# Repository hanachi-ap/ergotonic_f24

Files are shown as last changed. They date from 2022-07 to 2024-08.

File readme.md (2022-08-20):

# Ergotonic F24

Ergotonic F24 comes with a unique adjustable centerpiece making this keyboard split or monoblock on demand.
The Ergotonic F24 extends 30 mm horizontally and allows an adjustment of ±8 degrees with regards of the slant angle. In addition, it can also be completely separated and used as a true split.

- [About Ergotonic F24](https://hanachi-ap.github.io/ergotonic_f24/) (in Japanese)

- [How to build](https://hanachi-ap.github.io/ergotonic_f24/docs/) (in Japanese)

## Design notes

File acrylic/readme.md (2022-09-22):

## これは何?
このデータは Ergotonic F24 (v1r3)に装着するアクリルプレートの加工用データです。

左右のミドルプレートおよびボトムプレート、その他の修飾用部品が定義されています。

## アクリル素材寸法  
  450mm x 300mm x 2mm

## NOTE
- ミドルプレートを装着する場合、キーボード本体 PCBの裏側に突出しているTRRSコネクタ及びリセットスイッチの足の部分をニッパーでカットし平らになるよう加工してください。

## 利用許諾

- 個人で利用される限り自由にお使いください。

- 作成したプレートの販売などお考えの場合は事前にご相談いただけると幸いです。
  (モデルチェンジ等のタイミングなどの調整のため)

- データについては下記のライセンスで配布しています
 
    Creative Commons(CC BY-SA 4.0 by Hanachi-ap)

## Change notes
v1r3_1 からv1r3_2への変更点
- ミドルプレート Right SW28付近のネジ頭逃し用の穴が欠落していたミスを修正

v1r3 からv1r3_1への変更点
- ミドルプレートの Left SW19, Right SW27付近が他パーツと干渉しないよう形状を変更
- ミドルプレート Left SW23部分が他パーツと干渉しないよう形状を変更
- ミドルプレート ネジ頭逃し用のホールを干渉しない用大きめに変更
- 全体: ロータリエンコーダ使用のためのProMicroカバーのカットデータを追加
- 全体: おまけの丸いプレートを1個追加
-

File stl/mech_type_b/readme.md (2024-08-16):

# Parts to convert Ergotronic F24 to variable-sweep wing - Type B

Wing can be folded

## Required items
- Screws M2 5mm x4
- Screws M2 30mm x2

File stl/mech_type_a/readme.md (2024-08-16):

# Parts to convert Ergotronic F24 to variable-sweep wing - Type A

## Required items
- Screws M2 5mm x4

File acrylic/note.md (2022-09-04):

## これは何?
このデータは Ergotonic F24 (v1r3)に装着するアクリルプレートの加工用データです。

左右のミドルプレートおよびボトムプレート、その他の修飾用部品が定義されています。

## アクリル素材寸法  
  450mm x 300mm x 2mm

## NOTE
- ミドルプレートを装着する場合、キーボード本体 PCBの裏側に突出しているTRRSコネクタ及びリセットスイッチの足の部分を
ニッパーでカットし平らになるよう加工してください。

## 利用許諾

- 個人で利用される限り自由にお使いください。

- 作成したプレートの販売などお考えの場合は事前にご相談いただけると幸いです。

- データについては下記のライセンスで配布しています
  - Designed by  Hanachi-ap (hanachi.ap@gmail.com)
  - Creative Commons(CC BY-SA 4.0 by Hanachi-ap)

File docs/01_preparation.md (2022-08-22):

[<<Prev: Index](index.md) 

# 1. 準備

組み立てを始める前に、パーツおよびツールが揃っていることを確認します。

## キット添付品

|品名 (基本部) | 数量 |備考|
|:---|----:|----|
|PCB (プリント基板)  右 | 1枚 |  |
|PCB (プリント基板)  左 | 1枚 |  |
|トッププレート | 2枚 | 左右共通  |
|ボトムプレート | 2枚 | 左右共通  |
|ジョイントパーツ | 2枚 | 切り離して利用|
|ネジ(短) | 32本 | M2 3mm  |
|ネジ(長) | 16個  | M2 5mm |
|スペーサー(短) | 12個 | M2 3.5mm |
|スペーサー(長) | 12個 |  M2 7mm  |
|基板用コネクタ4P | 2個  | |
|コネクタ付きコード4P | 1個  | |
|ダイオード |48個  | 1N4148W  |
|TRRSジャック |2個 | |
|タクトスイッチ |2個  | |
|クッションゴム |10個  | |

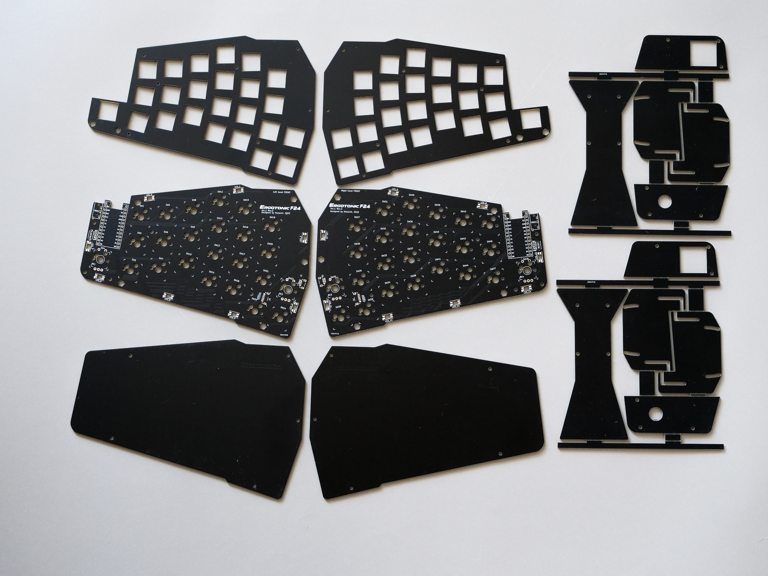
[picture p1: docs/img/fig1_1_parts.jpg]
プレート


## キット以外に用意するもの

|品名 | 数量 |備考|
|:---|----:|:---|
| ProMicro | 2個| Type-C版も可|
| コンスルー | 4個|  12ピン|
| MXスイッチソケット |48個|  |
 キーキャップ (1Uサイズ)  | 48個| |
 TRRSケーブル (4極オーディオ) | 1本 | 30cm以上推奨 |
 アンダーグロー用LED SK6812MINI-E |16個|オプション|
| ロータリーエンコーダー| 最大4個| オプション|

- 上記に上げたパーツはショップ店頭や通販で入手できます。  [パーツショップ(日本)](08_reference.md)に記した通販サイトからの購入が便利です。

- オプションと表記しているパーツは無くてもキーボードとしての基本機能は満たします。お好みに応じて準備して下さい。

- ロータリーエンコーダーは特定のキースイッチと排他で最大4個搭載できます。Alps EC12 またはEC11シリーズ互換のものを準備下さい。
日本国内で簡単に手に入るものとしては下記で動作確認しています。
   - [遊舎工房(ロータリーエンコーダ)](https://shop.yushakobo.jp/products/3762?_pos=1&_sid=5d7e3f999&_ss=r)
   - [秋月電子通商 【P-06357】ロータリーエンコーダ](https://akizukidenshi.com/catalog/g/gP-06357/)
    
   もし上記以外で動作を確認できた場合は作者にフィードバックいただけると幸いです。

## ツール
 - ハンダ道具一式
   - 糸ハンダ
   - はんだごて
   - フラックス
   - 周辺ツール(作業マット、コテ台、スポンジ、ハンダ吸い取り線、フラックス洗浄剤等)
 - ピンセット
 - 精密ドライバ(プラス No.0)
 - ラジオペンチ
 - カッターナイフ、定規、ヤスリ (PCB切り離し用) 
 - エポキシ系接着剤 (ProMicroの補強用。必要に応じて)
 - テスター  (可能なら必要に応じて)
 - 黒色のマジックペン (基板の側面の黒塗り用。必要に応じて)
  
----
[>>Next: ProMicroの準備](02_promicro.md)   

[Index](index.md)

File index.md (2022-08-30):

# Ergotonic F24 ドキュメント

Erogotonic F24は個人により開発されている自作向けメカニカルキーボードです。

## Ergotonic F24の特徴

### 左右分離型メカニカルキーボード
  - 片手 24キー 合計48キーを搭載
  - テンキー、カーソルキー、ファンクションキー、及び数字行が省かれた 40% レイアウトに相当
  - Cherry MX互換キースイッチのホットスワップに対応しているため、組み立て後も気分や状況に応じてスイッチを取り替えることが容易です。
 
### Willow配列
  - 緩やかにカーブを描いた独特のキー配列は、従来は3D構造でしか実現できていなかったエルゴノミクス的なエクスペリエンスを平面上の構造に再現しています。
  - それぞれの指を動かす際の動的な軌跡に最適化しており、目的のキーに指がすっと自然に到達する感覚が得られます
  - 親指周りに潤沢にキーを配置し、スペースキー以外にシフトキー、コントロールキーなどよく利用するキーを親指でコントロール可能とするレイアウトです
  
### 合体&変形ギミック
  
  分離型のキーボドードを一体型として利用するためのパーツを同梱。組み立て後も分離型、一体型どちらにも容易に移行できます。  また更に 左右に拡張、上下に角度をつける機構が組み込まれているので、利用者の着座姿勢や打鍵ポジションに応じてキーボードの形状を自在に変化させることができます

  -  分離型
     
     普通のスプリットキーボードとして、自在な置き方で利用できます
  
  -  一体型
  
     左右を合体させた場合は、定評のあるErgotonic49 とほぼ同じ形状となります 
  
  -  拡張形態
     
     一体型の基本形から左右に 最大30mm拡張
  
  -  前進翼形態
     
     あるいは翼を広げた鳥のようなシルエット
  
  -  後退翼形態
     
      または未来少年コナンに登場する飛行要塞ギガント

### 光るキーボード
  - アンダーグローLED(オプション)が艶やかな光でデスクを演出します

### フルキーカスタマイズ
  - すべてのキーは自由にカスタマイズが可能
  - 画面上でキーをドラッグ&ドロップするだけの簡単操作です
  - Chromeブラウザ上で操作できるため専用のアプリのインストールは不要です
  - アーダーグローLEDの光の設定やマクロ文字列の定義も簡単に行なえます 

### ロータリーエンコーダーを搭載可能
  - オプションで最大4個のロータリーエンコーダーを搭載することができます(キースイッチと排他)
  - ロータリーエンコーダーは、 拡大/縮小、上下スクロール、左右スクロール、キャンパス回転、ブラシ拡縮、音量ボリューム調整など、多彩な機能をユーザの好みで自在に割り当てることができます。

### オーソドックスな組立方式
  - 日本の自作キーボード界隈でよく採用されているFR4プレート3枚のサンドイッチ構造
  - マイクロプロセッサには入手性と取り扱いが容易なProMicroを採用
  - ファームウェアには多彩な機能が実装可能なQMK Firmwareを採用

## 作成方法

- [ビルドガイド](docs/index.md)

  - これは利用者自らが組み立てを行う必要のあるキットとして頒布されます。
  - キーボードの組み立てを始める前に全体工程をよく理解してから取りかることをおすすめします。

## 権利関係など

下記のライセンスにて公開します

  - QMK Firmware -- GPL v2
  - PCB デザイン -- GPL v3
  - [キー配列(Willow配列)](docs/ergotonic_f49_layout_desigen.pdf )-- Creative Commons(CC BY-SA 4.0 by Hanachi-ap)   

## ベースとなったプロダクト
  - Ergotonic49 
    - Ergotonic F-24と同じ開発者による現行モデル
    -  ドキュメント https://hanachi-ap.github.io/ergotonic49_docs/
    -  紹介記事 https://coal.hatenablog.com/entry/2021/11/01/230327
  - PANGAEA Keyboard
    - 開発リソース https://github.com/e3w2q/Pangaea-keyboard
    - 開発陣 e3w2qさん、オタヒーのさめさん、k2さん
    - 変形機構のアイデアや実装を借用しています
    - PCB設計のための部品ライブラリを利用させてもらっています
    - その他、豊かな発想から開発の養分を得ています
  
変形ギミックが特徴的なキーボードですが、その変形機構は[PANGAEA Keyboard](https://github.com/e3w2q/Pangaea-keyboard)が発想の源となっています。
一体型、分離型のトランスフォームはWillow64を始めた頃からやりたかったことですが、やっとその目標を結実することができました。
変形機構の利用を快諾していただいたPANGAEAキーボードの開発陣に謝意を送ります。

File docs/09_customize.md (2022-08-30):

# キーボードをカスタマイズする

##  標準キーマップ

標準ファームウェアでは0から4までの5つのレイヤーが定義されています。

 - レイヤー0  : 基本のアルファベット
 - レイヤー1  : 未定義
 - レイヤー2  : 数字、記号
 - レイヤー3  : カーソル移動、ファンクションキー
 - レイヤー4  : LED操作などキーボードシステム設定

Erogotonic49には物理的な数字キーはありませんが、レイヤー変更キーを押しながらQを押すと1が入力されるというような動作が可能です。

また レイヤー1 はなにもキーコードが定義されていない状態になっています。これはWindowsとMacの使い分け、オフィス作業とゲーム操作の使い分け、特定のアプリのショートカットなど自由に定義できるレイヤーとして使って下さい。

その他にも色々な機能があるので、 チートシート [keymap_cheatsheet_ergotonic_49.pdf](img/keymap_cheatsheet_ergotonic_49.pdf)を参照して確認してみて下さい。

----
自分が使いやすいと思うように自由にカスタマイズすることは自作キーボードの楽しみの一つなので、標準キーマップにとらわれず色々と試してみるのが良いと思います。

Ergotonic49をカスタマイズする方法は、大きく次の2つの方法があります。
  1. [REMAP](https://remap-keys.app/)を用いて、直感的にキーマップを変更する方法
  2. [QMK Firmware](https://docs.qmk.fm/)を編集して詳細なカスタマイズを行う方法

## 1. REAMPをつかう

キー配列を変更したり、LEDの点灯を変更したりするにはREMAPがあれば十分だと思います。

キーボードとPCをつないだ状態でChromeブラウザで[https://remap-keys.app/](https://remap-keys.app/)にアクセスして下さい。

サイトは英語表記だけですが、操作方法は直感的なので特に説明が無くても解ると思います。アカウント登録するとキーマップを保存したり読み込んだりできるので便利です。

## 2. QMK Firmwareを編集する

Ergotonic F24は[QMK Firmware](https://docs.qmk.fm/)というオープンソースとして開発されているファームウェアを利用しいています。

QMKにはとても沢山の機能が用意されていて、より自由な設定を行うことができます。
しかしそのためにはプログラミング言語(C言語)やPC上での黒い画面(コンソール)でコマンドを使ったコンパイル操作を行う必要があります。

Ergotonic F24のファームウェアは [ここ](https://github.com/hanachi-ap/ergotonic_f24)から参照できます。
もしこれを見て行けそうだ! と感じたらぜひQMK Firmwareのカスタマイズに挑戦してみて下さい。

----
 [Index](index.md)

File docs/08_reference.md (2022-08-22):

 [Index](index.md)

# 参考情報

## パーツショップ(日本)

キット以外に必要なパーツは自作キーボードの代表的な下記ショップで揃えることができます。

- 遊舎工房 [https://yushakobo.jp/](https://yushakobo.jp/)
- TALP KEYBOARD [https://talpkeyboard.stores.jp/](https://talpkeyboard.stores.jp/)
- LiLaKEY [https://lilakey.com/](https://lilakey.com/)
- 秋月電子通商 [https://akizukidenshi.com/catalog/default.aspx](https://akizukidenshi.com/catalog/default.aspx)
  
## はんだ付け技能
下記以外にも様々なテクニックやノウハウが公開されているので、各個のスキルに応じて検索サイトで調べるようにしてください。

- [はんだ付けテクニックを学ぼう](https://handa-craft.hakko.com/) HAKKO
- [電子工作のコツ/はんだ付け ](https://article.murata.com/ja-jp/article/soldering)村田製作所
- [ハンダ付け職人のはんだ付け講座](https://godhanda.co.jp/blog/category/handakouza/soldering%E3%80%80guide/) ゴッドはんだ株式会社
- [表面実装部品（SMD）のはんだ付け](https://www.kogadenshi.co.jp/%E5%8D%8A%E7%94%B0%E4%BB%98%E3%81%91%E3%83%86%E3%82%AF%E3%83%8B%E3%83%83%E3%82%AF/%E8%A1%A8%E9%9D%A2%E5%AE%9F%E8%A3%85%E9%83%A8%E5%93%81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) 株式会社古賀電子

----
 [Index](index.md)

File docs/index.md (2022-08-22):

# Ergotonic F24 組み立て説明書

Ergotonic F24のビルドガイドです。

キーボードの組み立てを始める前に全体工程をよく理解してから取りかることをおすすめします。

## TOC

1. [準備](01_preparation.md)  
2. [ProMicroの準備](02_promicro.md)
3. [PCBへのパーツ取り付け](03_soldering_pcb.md)
4. [組立前の動作確認](04_operation_check.md)
5. [組み立て](05_assembly.md)
6. [最後のステップ](06_final_step.md)
7. [トラブルシュート](07_troubleshoot.md)

- [Ergotonic F24の使い方、キーマップのカスタマイズ方法](10_usage.md)
 
- [参考情報(外部リンク)](08_reference.md)

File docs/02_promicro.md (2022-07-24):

[<<Prev: 事前の準備](01_preparation.md)  

# 2. ProMicroの準備

## ProMicroにコンスルーをはんだ付けする

- スプリングピンヘッダの足の長い方をPCBのスルーホールへ差し込みます。
- ProMicroの部品が実装してある面が内側に隠れるような向き(平らな面が見える向き)でピンヘッダに差し込みます
- ProMicro側のピンヘッダをはんだ付けします。

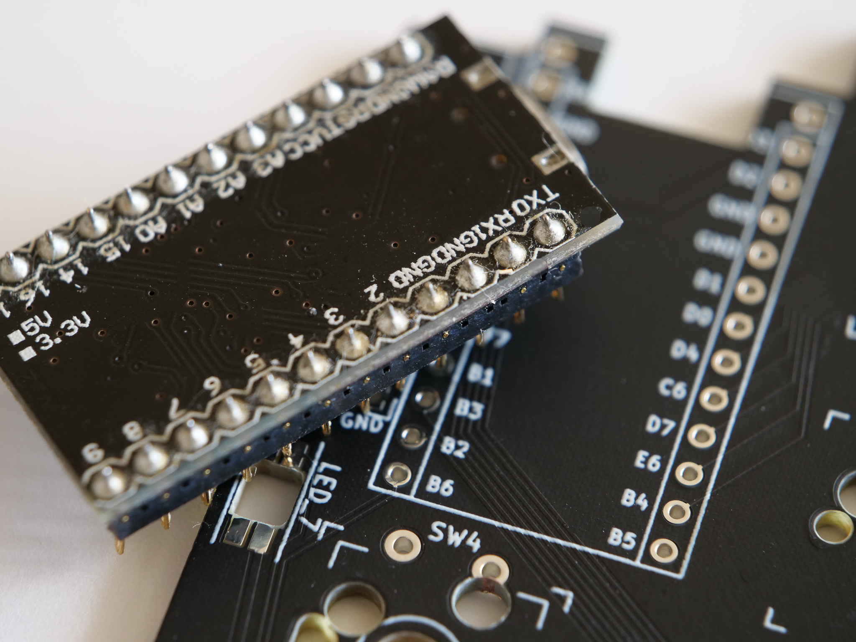
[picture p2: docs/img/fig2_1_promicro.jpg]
ProMicro
  

NOTE
- PCB側のピンヘッダははんだ付けしません。はんだ付けするのはProMicro側だけです。
- ProMicroの表裏を間違えるとリカバリが非常に大変ですのではんだ付けの前に向きに注意ください。

TIPS:
 - [ProMicroへコンスルーの取り付け方(遊舎工房)](https://yushakobo.zendesk.com/hc/ja/articles/360044233974-%E3%82%B3%E3%83%B3%E3%82%B9%E3%83%AB%E3%83%BC-%E3%82%B9%E3%83%97%E3%83%AA%E3%83%B3%E3%82%B0%E3%83%94%E3%83%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)

## USBコネクタ周辺を補強する(オプション)

ProMicroはUSBコネクタ部分の強度が弱いことが知られています。
対策としてProMicroのUSBコネクタ部分をエポキシ系接着剤の樹脂で強化します。
 - エポキシ系接着剤の説明書の指示通りに調合し、爪楊枝の先などで慎重にUSBコネクタ周辺に盛り付けます。
 - 樹脂が硬化するまで安静にします。

TIPS:
  - [もげマイクロ対策(Google search)](https://www.google.com/search?client=firefox-b-d&q=%E3%82%82%E3%81%92%E3%83%9E%E3%82%A4%E3%82%AF%E3%83%AD)
  - 2液タイプのエポキシ系接着剤は100円ショップでも手に入ります。

----
 [>>Next: PCBへのパーツ取り付け](03_soldering_pcb.md)

 [Index](index.md)

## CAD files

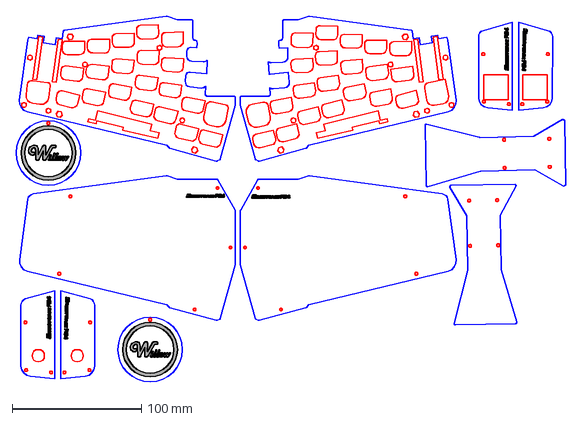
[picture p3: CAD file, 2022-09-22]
acrylic/ergotonic_f24_v1r3_2_acrylic_cut.dxf
425.9 x 283.2 mm

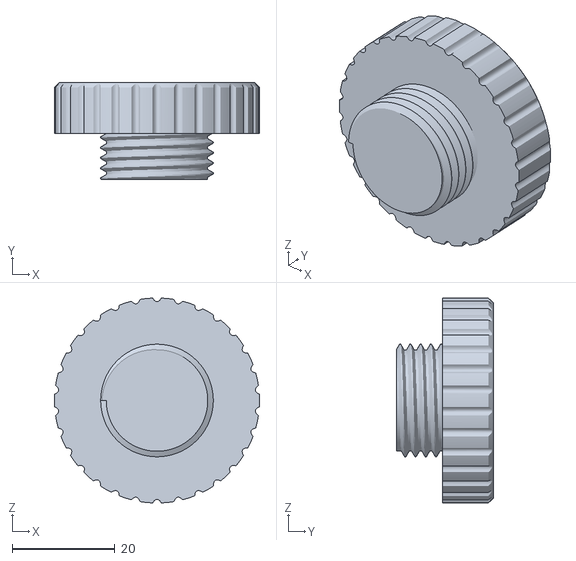
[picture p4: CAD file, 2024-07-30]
stl/mech_type_a/f24 - knob.stl
40.0 x 19.0 x 40.0

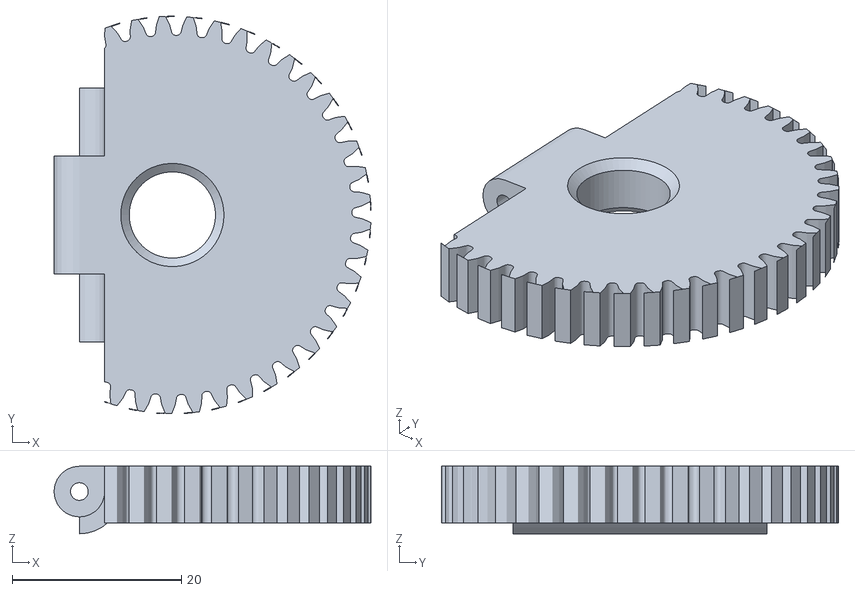
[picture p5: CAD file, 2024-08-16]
stl/mech_type_b/f24 - gear-r.stl
37.5 x 47.0 x 8.00

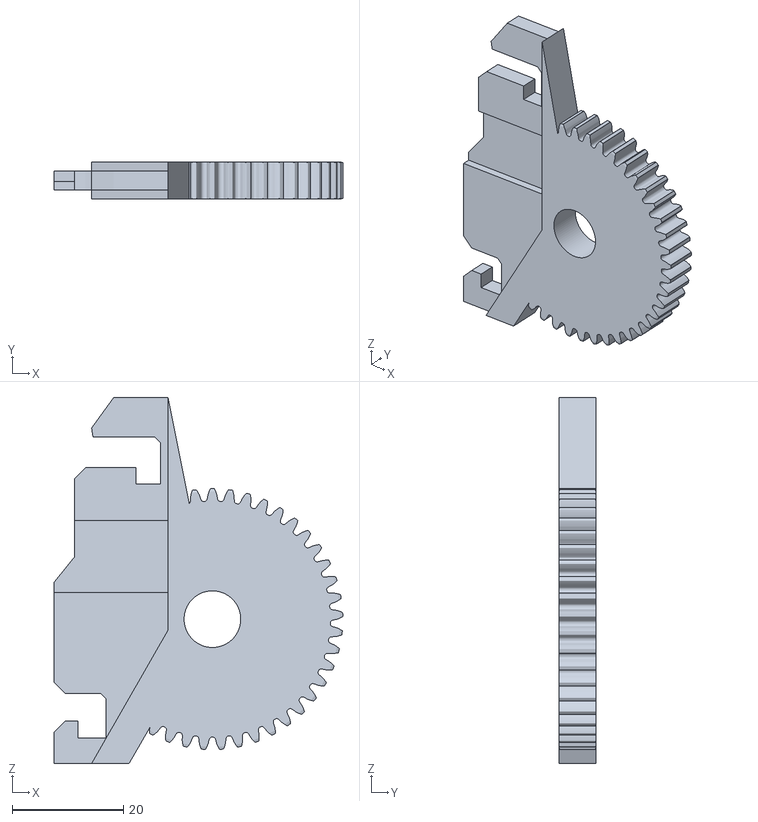
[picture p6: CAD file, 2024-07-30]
stl/mech_type_a/f24 - wheel-l.stl
52.0 x 6.70 x 65.9

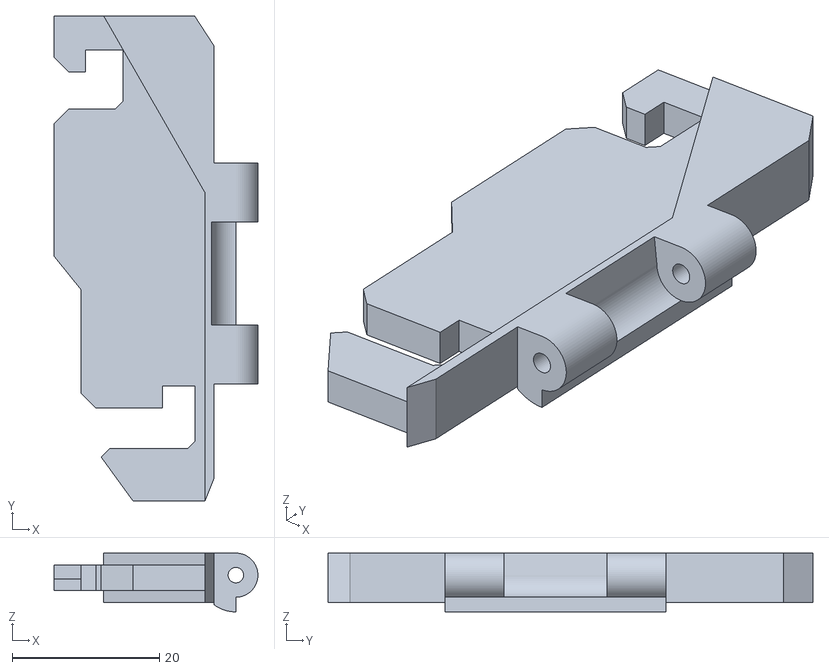
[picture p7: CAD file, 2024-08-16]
stl/mech_type_b/f24 - drumette-l.stl
27.7 x 65.9 x 8.00

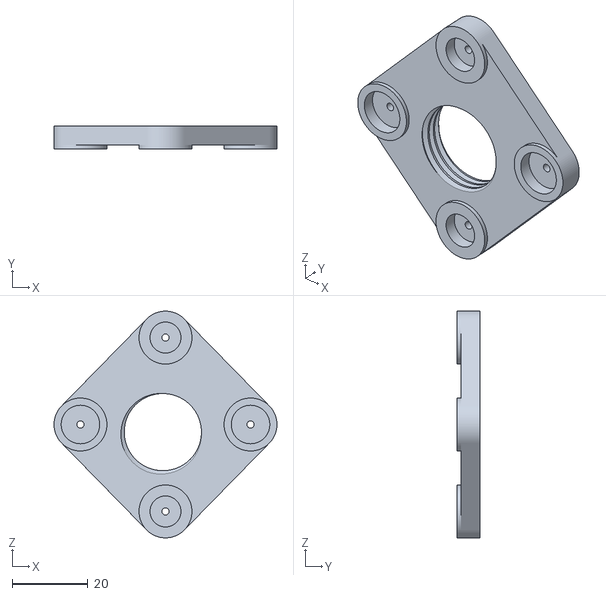
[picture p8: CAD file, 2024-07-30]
stl/mech_type_a/f24 - top.stl
59.0 x 6.00 x 60.0

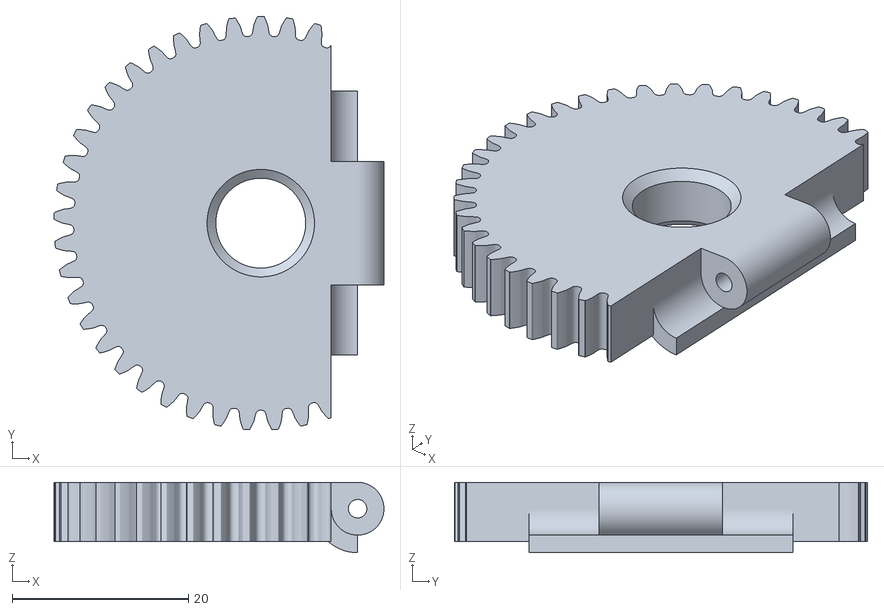
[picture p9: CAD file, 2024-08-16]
stl/mech_type_b/f24 - gear-l.stl
37.5 x 47.0 x 8.00

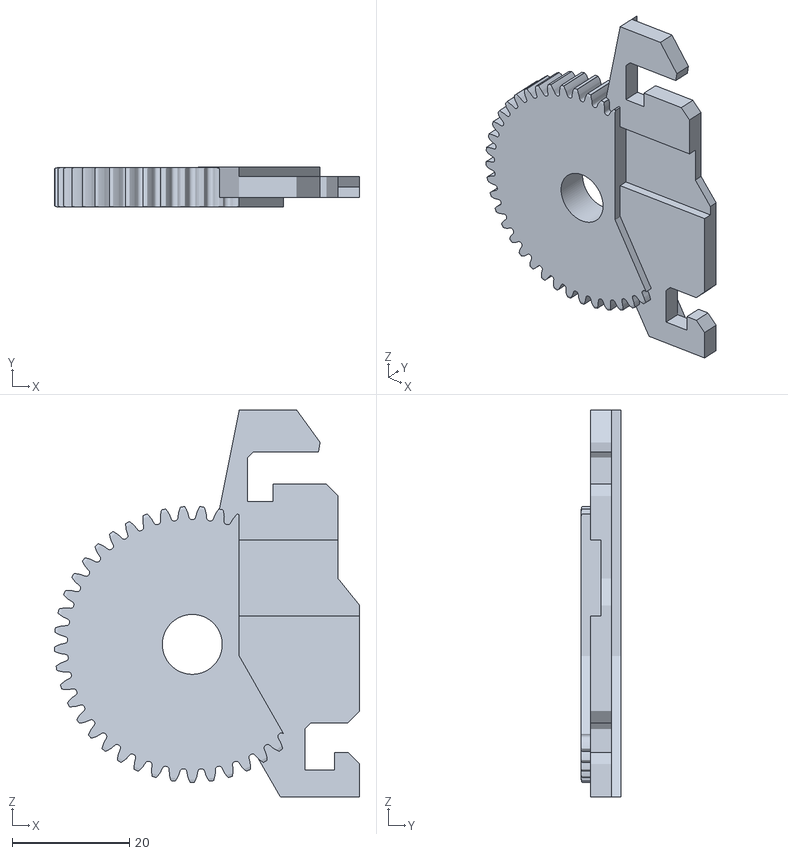
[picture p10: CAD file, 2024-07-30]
stl/mech_type_a/f24 - wheel-r.stl
52.0 x 6.80 x 65.9

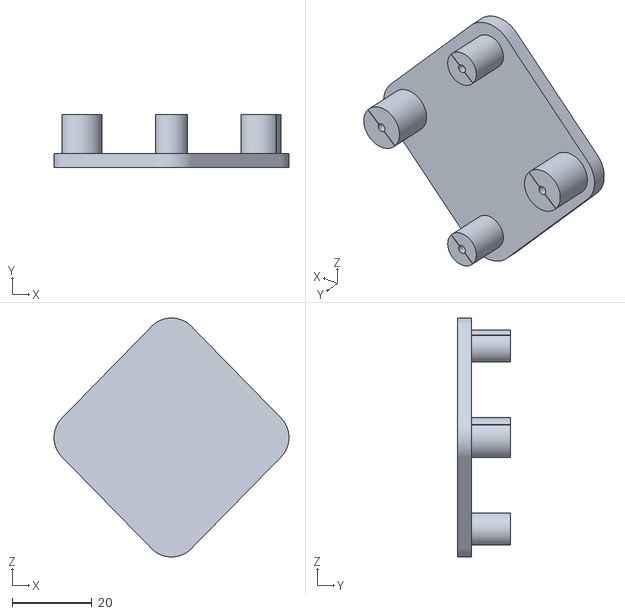
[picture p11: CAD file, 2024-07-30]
stl/mech_type_a/f24 - base.stl
59.0 x 13.2 x 60.0

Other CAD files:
stl/mech_type_b/f24 - drumette-r.stl

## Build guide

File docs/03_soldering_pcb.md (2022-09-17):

[<<Prev: ProMicroの準備](02_promicro.md)  

# 3. PCBへのパーツ取り付け

- PCBは、左側と右側で種類が分かれています。このページの操作は左右それぞれのPCBに対して作業を行ってくだい。

- PCBへのパーツを取り付ける際にはPCBの左右、表裏に注意して下さい。プリントされている表記で判断出来ます。

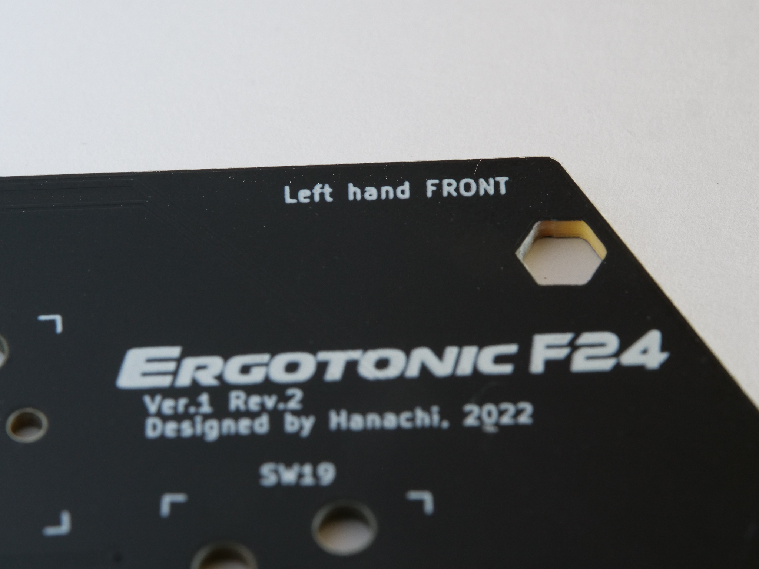
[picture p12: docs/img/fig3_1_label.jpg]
   

## ダイオードをはんだ付けする

電流の流れを制御するダイオードをはんだ付けします。

- ダイオードはPCBの裏面から取り付けます。
- ダイオードには極性があります。LEDに薄い線が印刷されている方向(カソード)をPCBシルクに合わせて配置します。
  
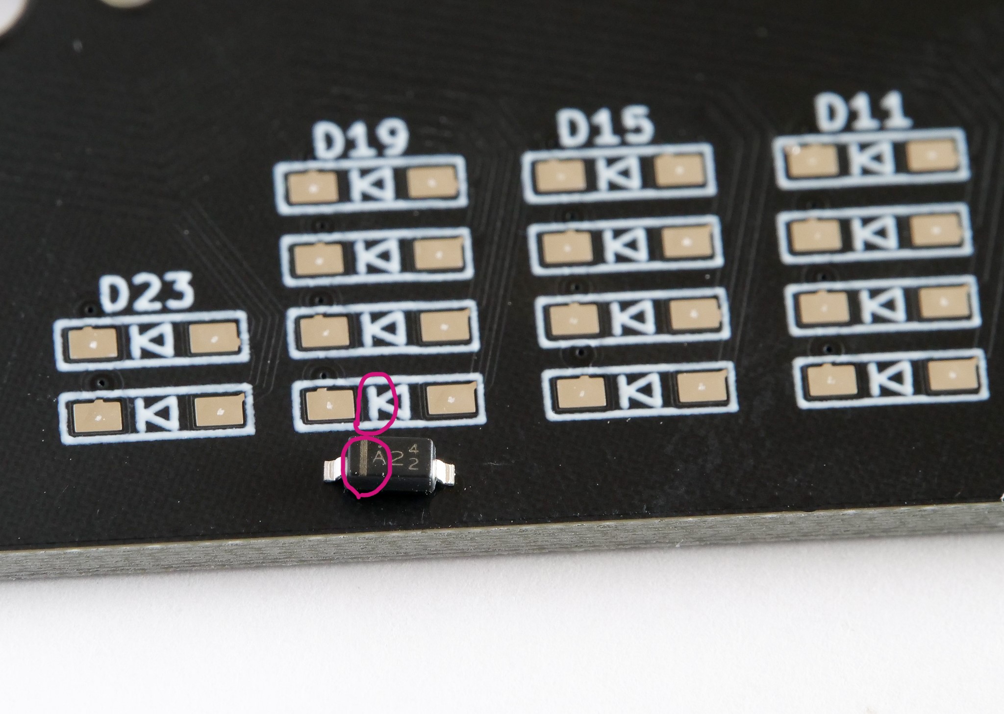
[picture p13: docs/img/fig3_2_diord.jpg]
   

- 両端2ヶ所をはんだ付けします。

TIPS:

- SMD型ダイオードのはんだ付けのコツ
  - PCBのパッドの片方に予備ハンダを盛ります
  - 予備ハンダを溶かしつつピンセットでダイオードを所定の位置に送ります
  - 反対側をはんだ付けします
  - 予備ハンダをした方をもう一度はんだ付けします
  
NOTE:

 - ダイオードの方向を間違わないよう気をつけて下さい。
 - キーが反応しないというトラブルの多くはダイオードのハンダ不良に起因します。はんだ付けの後に目視確認をしっかり行って下さい。
   - ハンダを忘れている部分がないか
   - はんだ付け不良の部分はないか
   - ダイオードの方向に間違いはないか

## アンダーグローLEDをはんだ付けする(オプション)

キーボードの下を装飾するアンダーグローLEDをはんだ付けします。

- PCBの裏面のLED_0、LED_1、LED_2とシルク印刷されている箇所に取り付けます。
  - PCBの表側から、光る面が裏側(下向き)になるように配置します。
  - LEDには極性があります。LEDの足が欠けている方向をシルクの印に合わせます。
  
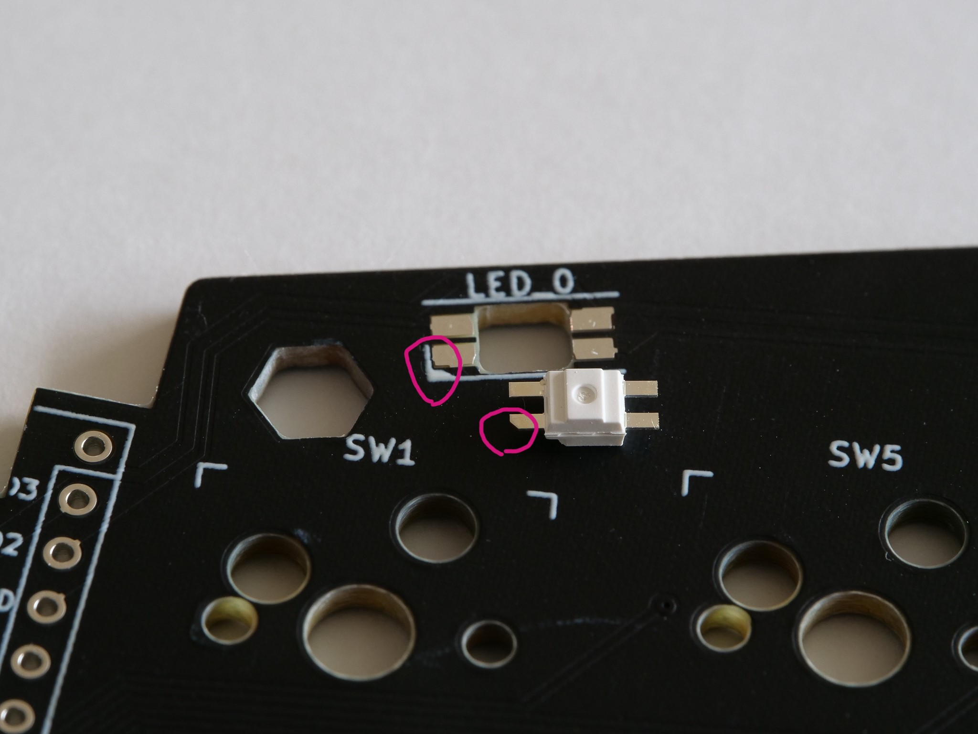
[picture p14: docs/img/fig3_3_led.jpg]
  

-  LEDの4ヶ所の足をはんだ付けします。

TIPS:

- LEDの取り付けと同時に光るかどうかを確認していくにはProMicroの環境を先に整えて、LED設定を RGB TESTモードに設定すると確認が行いやすくなります。

NOTE:

 - LEDの表裏、方向を間違わないよう気をつけて下さい。
 - 一度はんだ付けした後だと取り付け方向を修正するのは非常に困難になります。
  はんだ付けの前にしっかりと取り付け方向が正しいことを確認するようにして下さい。
 - RGB LEDは熱に弱いため、高温で長時間はんだ作業をしないよう注意して下さい。
 - LEDは番号の順に数珠つなぎで接続されています。光らない場合は番号順に調べていくようにしてください。

トラブルシュート:
  - [LEDが点灯しない](07_troubleshoot.md)

## スイッチソケットをはんだ付けする

キースイッチを取り外し可能にするソケットをはんだ付けします。

- PCBの裏面からシルクに合わせて取り付けて、2ヶ所をはんだ付けします。
  
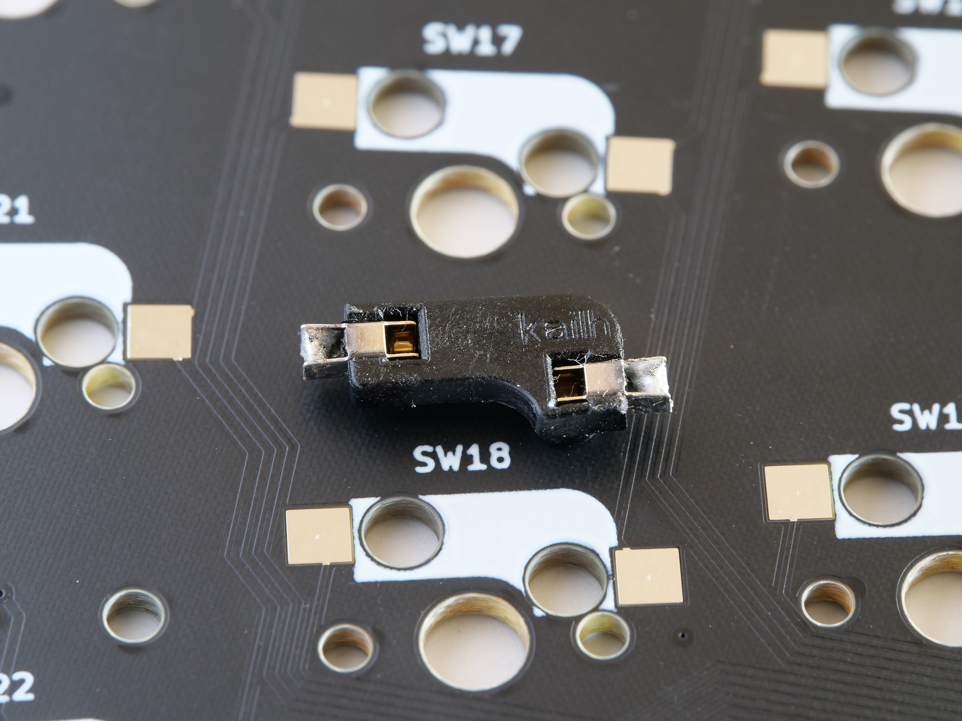
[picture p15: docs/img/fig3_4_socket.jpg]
MXスイッチソケットは裏側からはんだ付け
  

## リセットスイッチをはんだ付けする

- PCBの表側からタクトスイッチを取り付けます(極性はありません)
- PCBの裏側からはんだ付けします
  
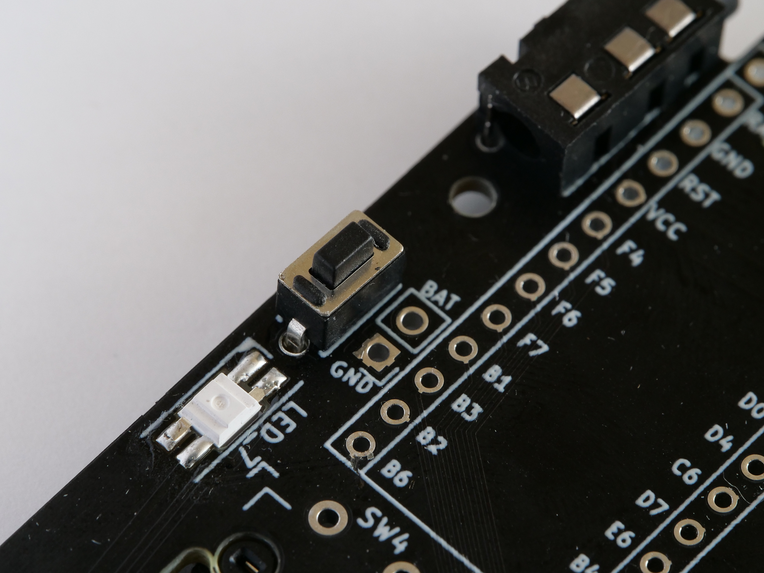
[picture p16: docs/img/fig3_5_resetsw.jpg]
リセットスイッチは表から挿して裏からはんだ付け
  

## TRRSジャックをはんだ付けする

- PCBの表側からタTRRSジャックを取り付けます。
- PCBの裏側からはんだ付けします
  
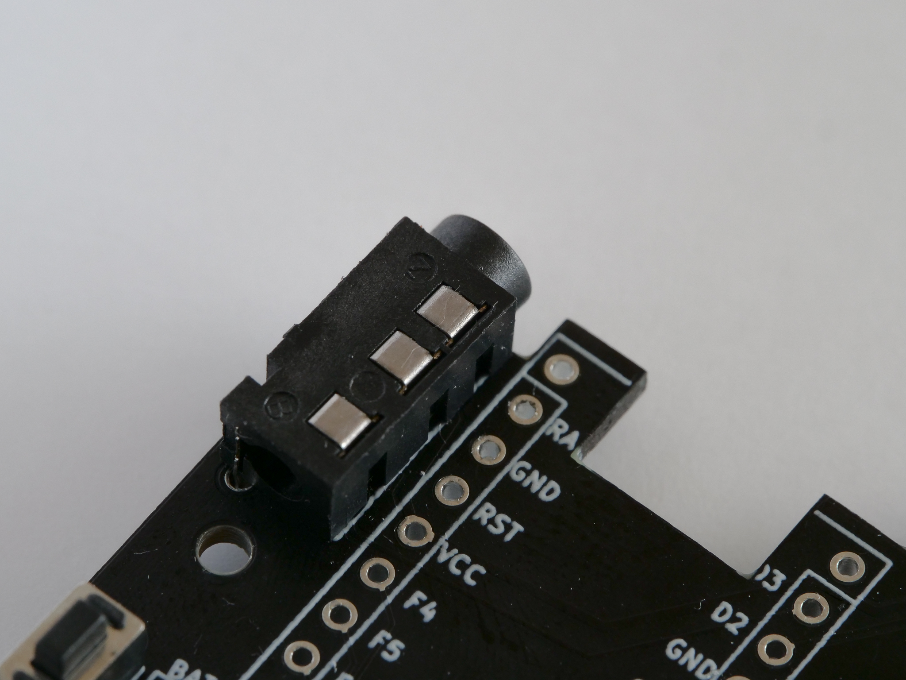
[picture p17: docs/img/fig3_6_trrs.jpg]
TRRSジャックは表から挿して裏からはんだ付け
  

## 基板用コネクタをはんだ付けする

- 左右のPCBをケーブルで結ぶためのコネクタをはんだ付けします。
- 若干難易度が高いので注意しながら進めてください。

下記は、作者が行っている方法です。

- PCBの表側に部品の位置を合わせマスキングテープで仮止めします

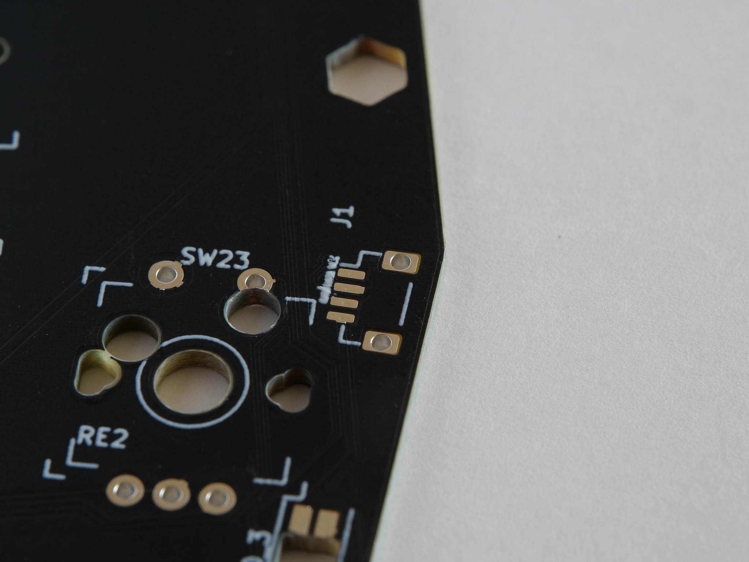
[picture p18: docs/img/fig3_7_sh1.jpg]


- PCBのパッドとコネクタの足の位置をしっかり見定め、コネクタの足を一本だけはんだ付けします
  - 2本以上の足をはんだ付けしてしまうと位置のリカバリが難しくなるので注意
  - この状態でコネクタを動かすとパッドごと剥がれてしまうことがあるので無理に動かさないように注意
- PCBの裏側のスルーホールからハンダを流し込みます。
  - スルーホールを通って表側までハンダが到達しコネクタをしっかりと接着していることを確認してください。
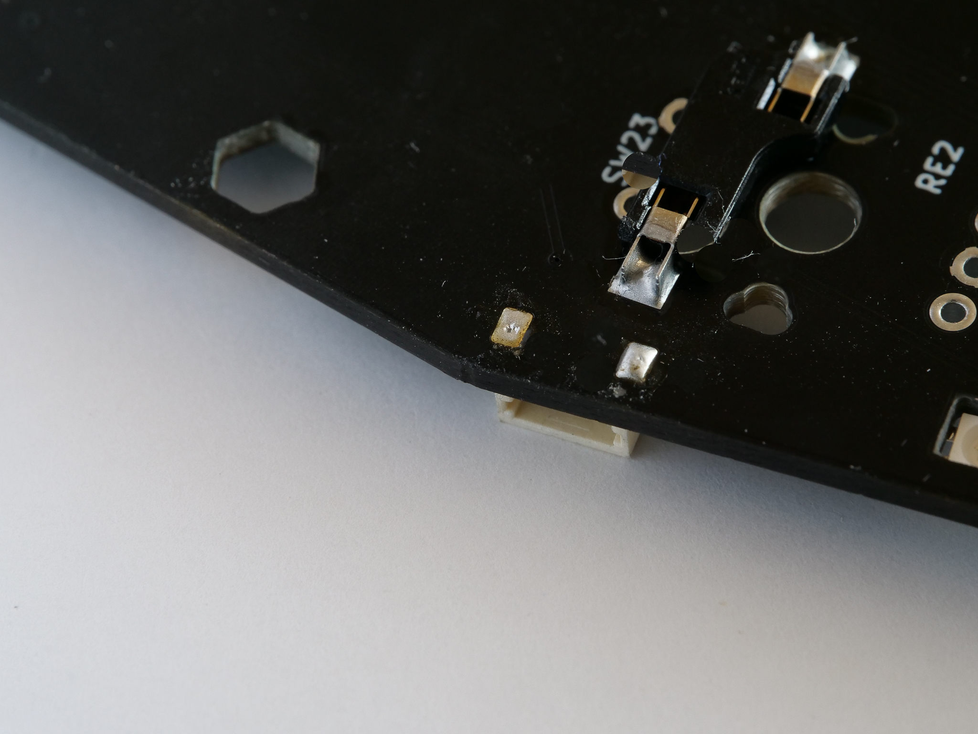
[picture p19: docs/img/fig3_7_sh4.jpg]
   

- PCB表側からコネクタの足の残りをはんだ付けします
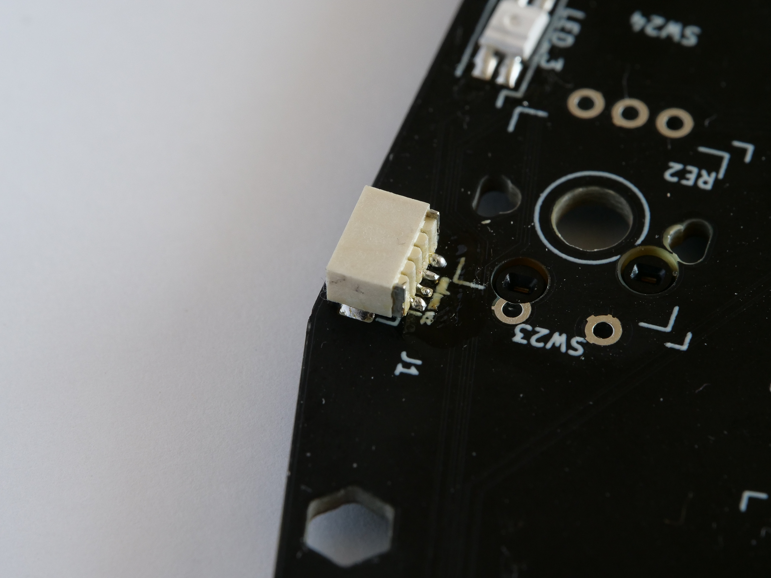
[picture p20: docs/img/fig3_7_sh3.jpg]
   

- TIPS

  基板端子のはんだ付けのショートムービを参照してください
  https://www.youtube.com/shorts/smUXss702QM

#### 注意
- 基板用コネクタにケーブルを差し込む前に、コネクタがしっかりとハンダで固定されれていることを確認するようにしてください。
- コネクタがしっかりと固定されていない状態でケーブルを差し込むと、基板からのネクタがポロッと外れてしまうだけでなく
  PCB内部の配線パターンごと剥がれてしてしまい、リカバリ不能な破損に繋がります。

## ロータリーエンコーダーを取り付ける

- ロータリーエンコーダーはRE1, RE2, RE3, RE4のシルク表記がある箇所に取り付けることができます。
- PCBの表側からパーツを取り付け、裏側をはんだ付けします。

----
 [>>Next: 組立前の動作確認](04_operation_check.md)

[Index](index.md)

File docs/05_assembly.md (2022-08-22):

[<<Prev: 組立前の動作確認](04_operation_check.md)  

# 5. 組み立て

はんだ付けが終わったパーツをキーボードの形に組み上げていきます。

## ジョイントパーツを切り離す
- ジョイントプレートのパーツを切り離して端面をヤスリがけしてなめらかにします。
  
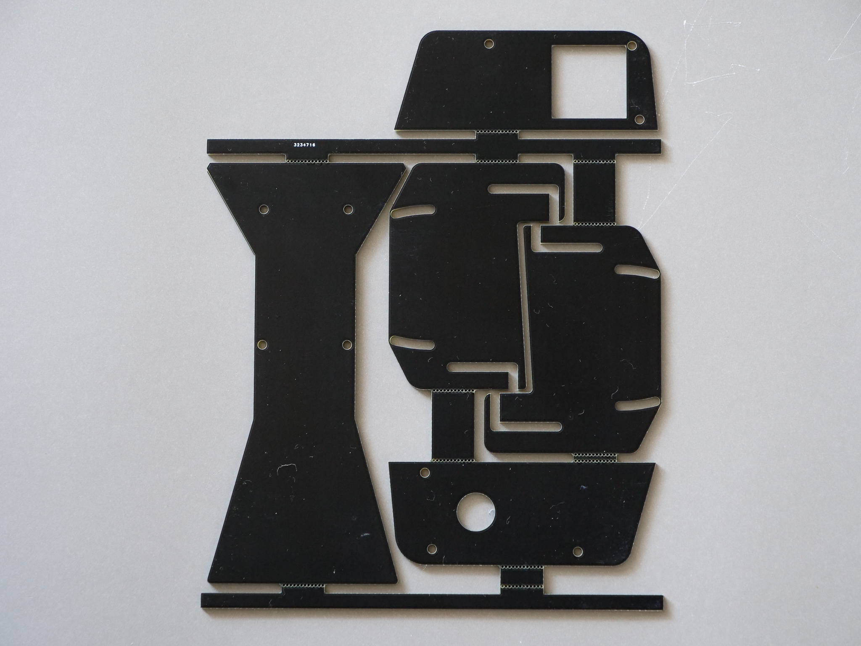
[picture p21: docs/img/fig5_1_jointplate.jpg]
  

## TIPS: 基板の側面を黒く塗る
- 基板の側面を表面と同じ黒色で塗装すると、組み立てた後にぐっと締まった佇まいとなります。オプション作業ですが、黒のマジックペンで基板側面を黒く塗ることをおすすめします

## PCBとトッププレートを結合する

- PCBにスペーサー(短)を2ヶ所ネジ止めします
  - 写真の位置に、表側にスペーサー(短)を配置し裏側からネジ(短)でねじ止めします。
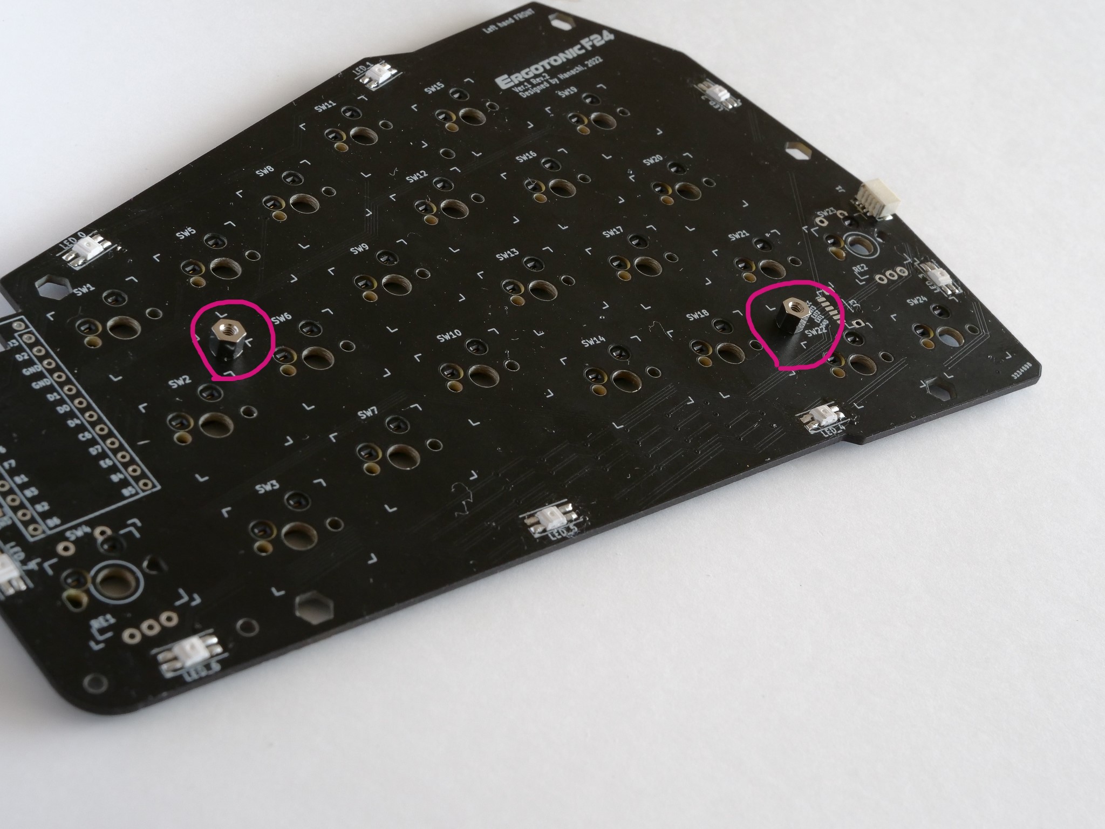
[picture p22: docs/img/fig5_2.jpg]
   
  
  - トッププレートを重ね、表側からも2ヶ所ネジ(短)でねじ止めします。
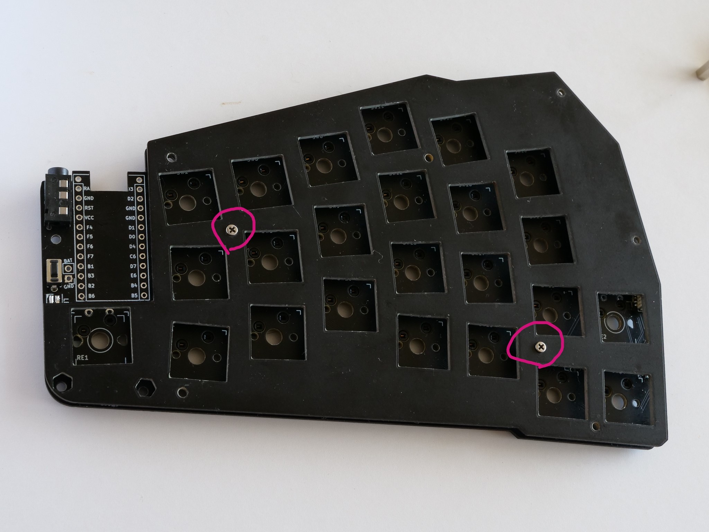
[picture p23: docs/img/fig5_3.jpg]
  

## スペーサー を取り付ける

- 全体を裏返し、PCBの六角形の穴の部分 Spacer(L)の指示の3ヶ所にスペーサー(長)を差し込みます
- PCBの六角形の穴の部分 Spacer(S)の指示の2箇所にスペーサー(短)を差し込みます。
  
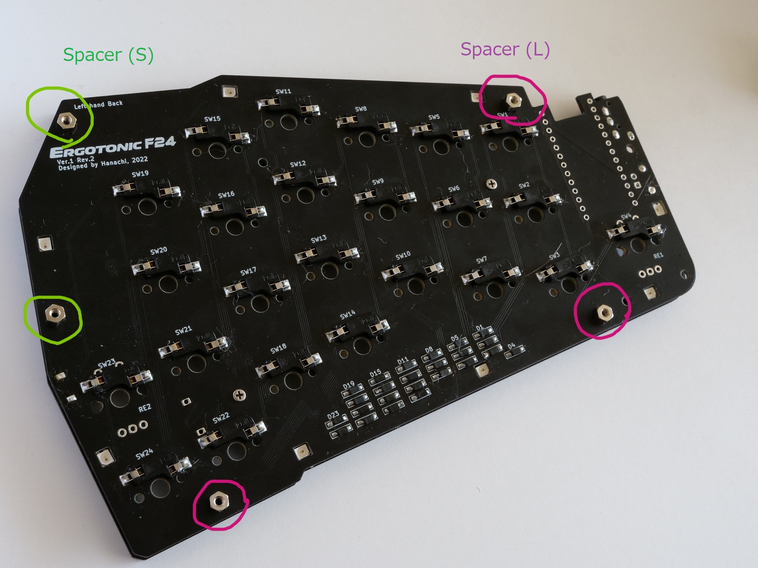
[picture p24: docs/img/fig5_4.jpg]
   
   
- トッププレート側からネジ止めします

  - Scew(S)の指示部分には、ネジ(短)を使用します
  - Screw(L)の指示部分には、ネジ(長)を使用します

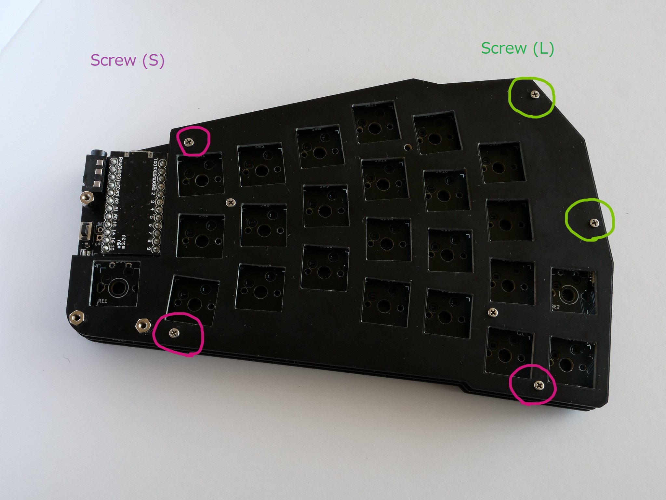
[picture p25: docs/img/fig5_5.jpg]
  

## PCBと保護プレートを結合する

- トッププレートの表側から、写真の位置にスペーサー(長)を配置し、PCBの裏側からネジ(短)で止めます
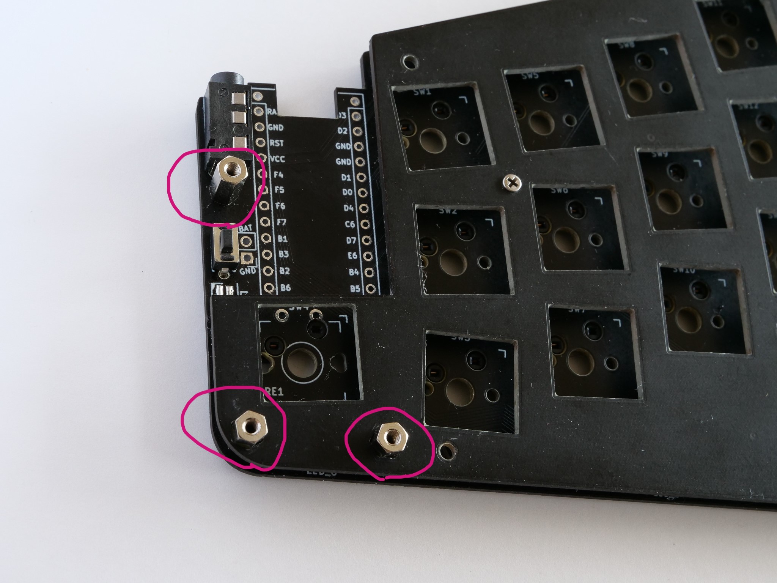
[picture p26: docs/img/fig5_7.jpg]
  
  
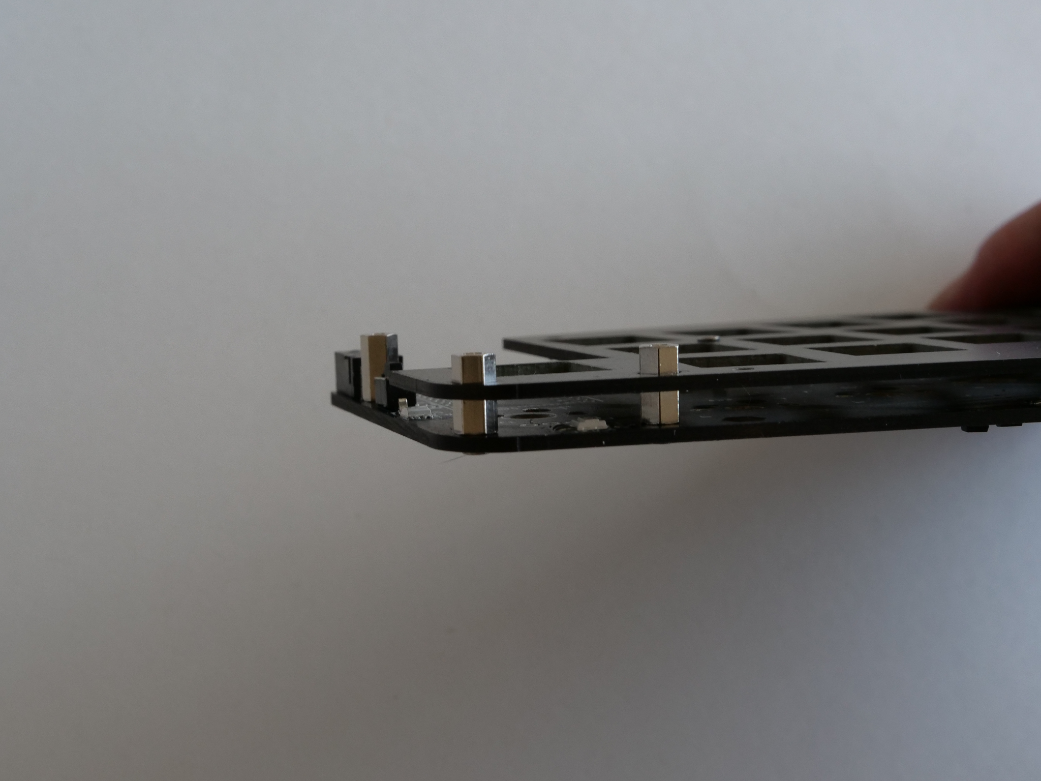
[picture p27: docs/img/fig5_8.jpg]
   

- 保護プレートを重ねて上から3ヶ所をネジ(短)で止めます。
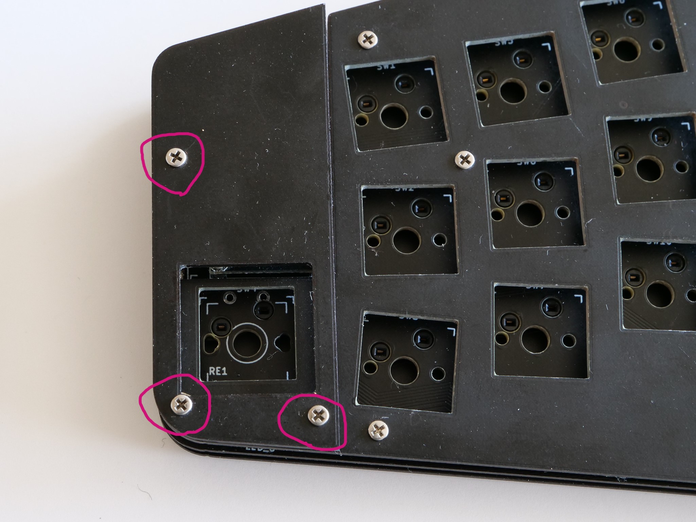
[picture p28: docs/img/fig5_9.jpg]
  

## ボトムプレートを結合する

- ボトムプレートを重ね 5ヶ所をネジ止めします
  - Scew(S)の指示部分には、ネジ(短)を使用します
  - Screw(L)の指示部分には、ネジ(長)を使用します
  - 
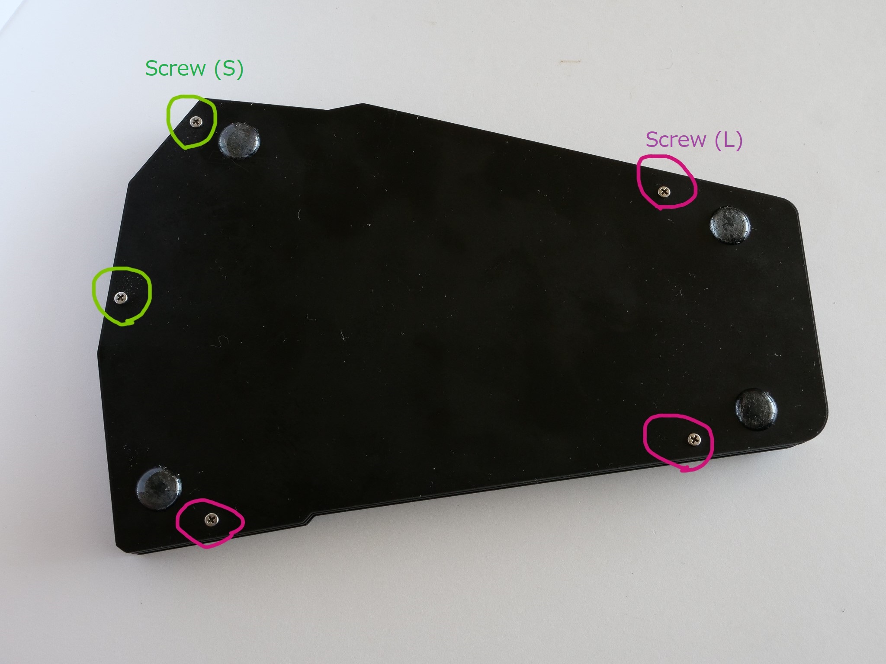
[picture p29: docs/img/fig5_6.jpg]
  

- スペーサー(短)の部分に関しては、横から見ると写真のように スペーサー(短)が中央部に浮いている状態になります。
  
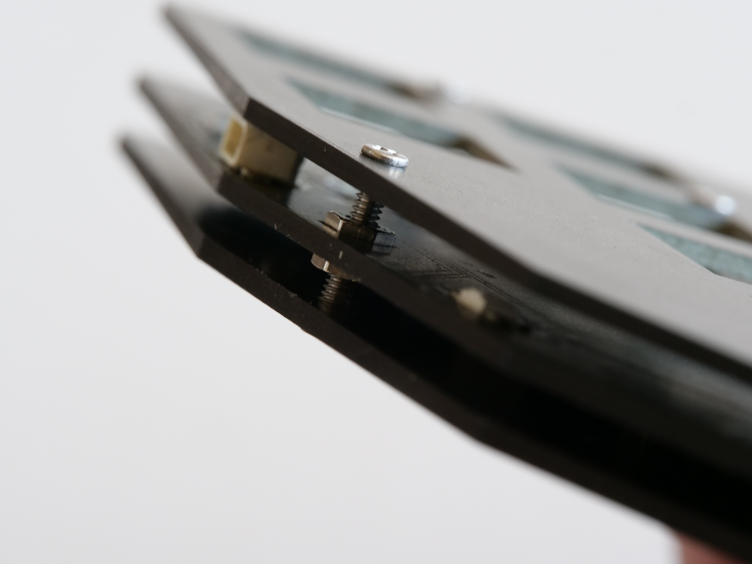
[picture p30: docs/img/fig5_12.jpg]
  

## [分離型で利用する場合]

### 三角スペーサージグを取り付ける
- プレートから切り出した三角形状のスペーサージグを2枚、プレートとスペーサー(短)の隙間に挟み込みネジを締めます。

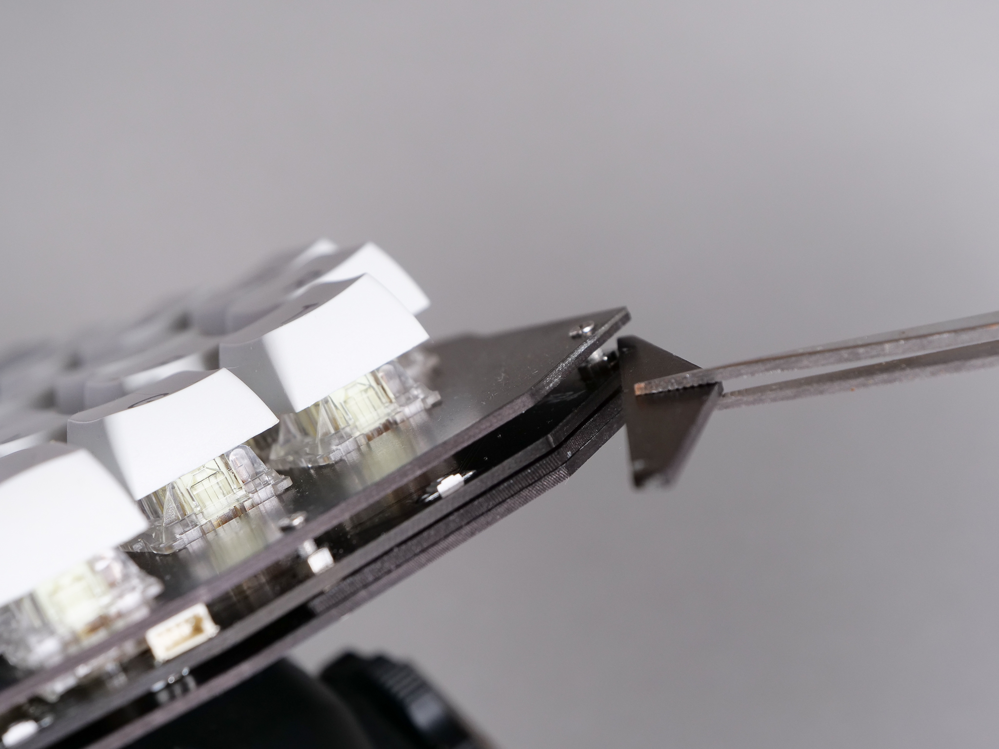
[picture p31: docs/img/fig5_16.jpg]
  

## [一体型で利用する場合] 

### ジョイントプレートを結合する

- ジョイントプレートをスペーサー(短)とネジ(長)を使い、図のように組み立てます
  
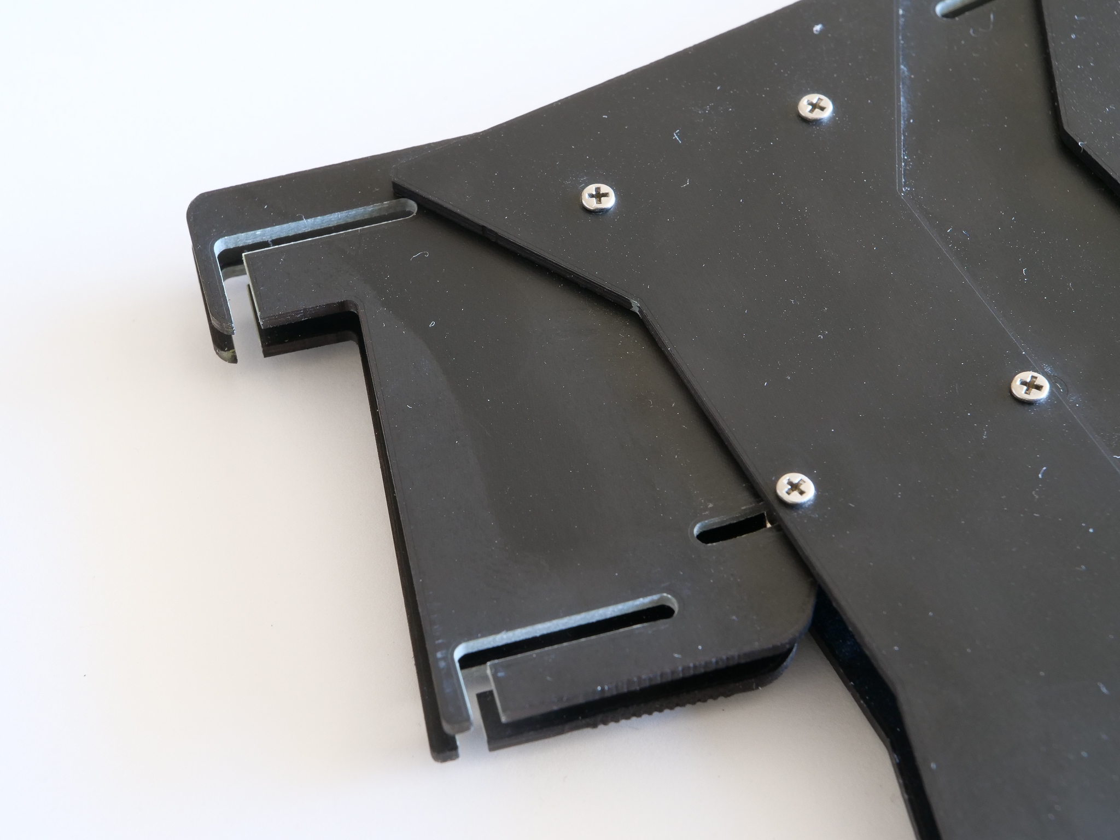
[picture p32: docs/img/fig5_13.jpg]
  

- ジョイントパーツのスリット部分を、先程のスペーサー(短)の隙間に通します。
  
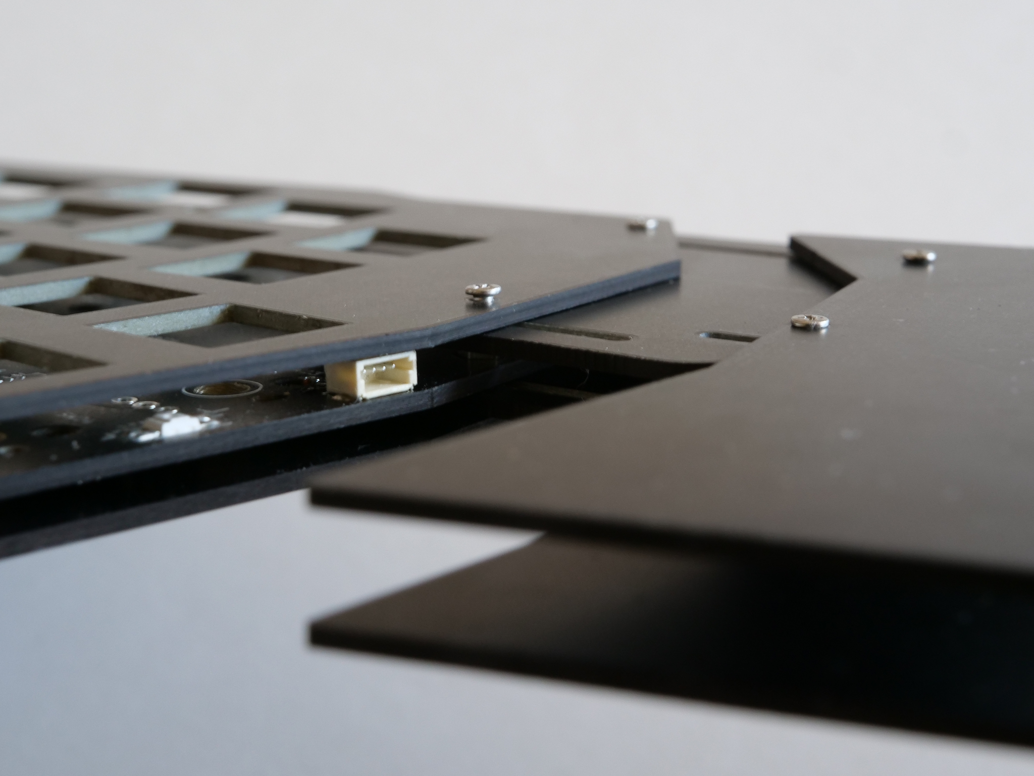
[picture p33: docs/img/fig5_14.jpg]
  

- コネクタ付きコード4Pをソケットに挿して左右を接続します。
  
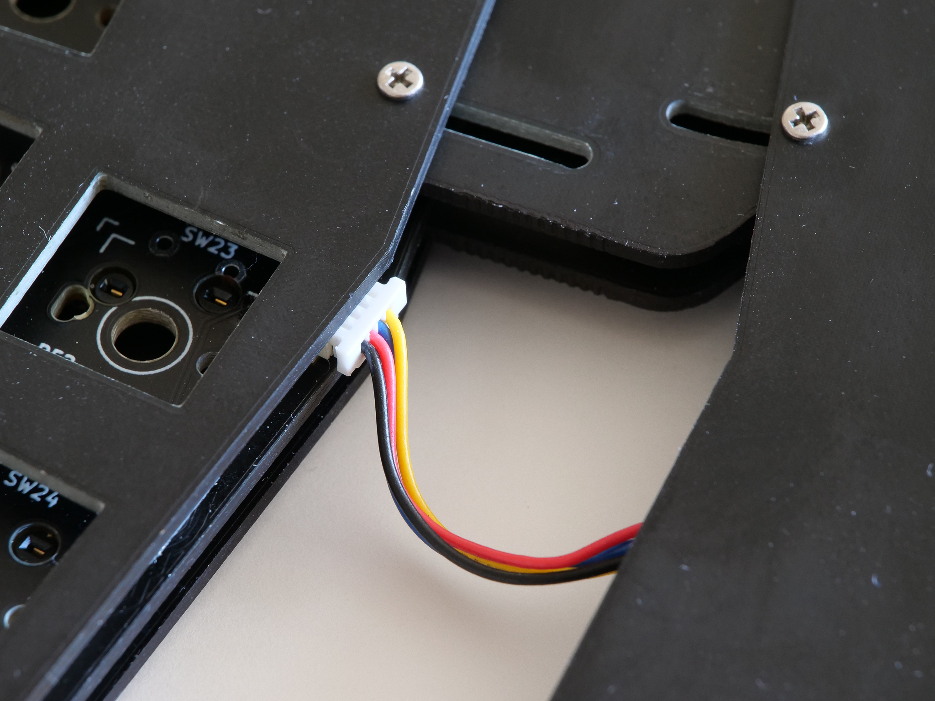
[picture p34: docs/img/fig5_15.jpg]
  

- ネジの締付けを調整しつつ好みの位置で固定します。
  
## ゴム足を取り付ける

- 裏側からゴム足を左右それぞれ4箇所、ジョイント部分に2箇所に取り付けます

----
 [>>Next: 最後のステップ](06_final_step.md)

[Index](index.md)

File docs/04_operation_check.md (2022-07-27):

[<<Prev: PCBへのパーツ取り付け](03_soldering_pcb.md)  

# 4. 組立前の動作確認

## ProMicroを取り付ける

PCBの表側からProMicroを取り付けます。

## ファームウェアを書き込む

下記の操作を左右2つ分のProMicroに対して行います。この段階ではまだTRRSケーブルやコネクタ付きコードで左右を連結しない状態にしておいてください。

- PCBに取り付けたProMicroとパソコンをUSBケーブルで接続します。

- ChromeもしくはEdge ブラウザで次のURLへアクセスします。

   [https://remap-keys.app/catalog/0vUSlf2gKOlRn1JkQjPH/firmware](hhttps://remap-keys.app/catalog/0vUSlf2gKOlRn1JkQjPH/firmware)

-  書き込みを行うファームウェア(ここでは ergotonic_f24_default.hex )の FLUSH 
   をクリックし、表示される操作方法(英語表記です)を確認し、さらにFLUSHを
   クリックします。
  
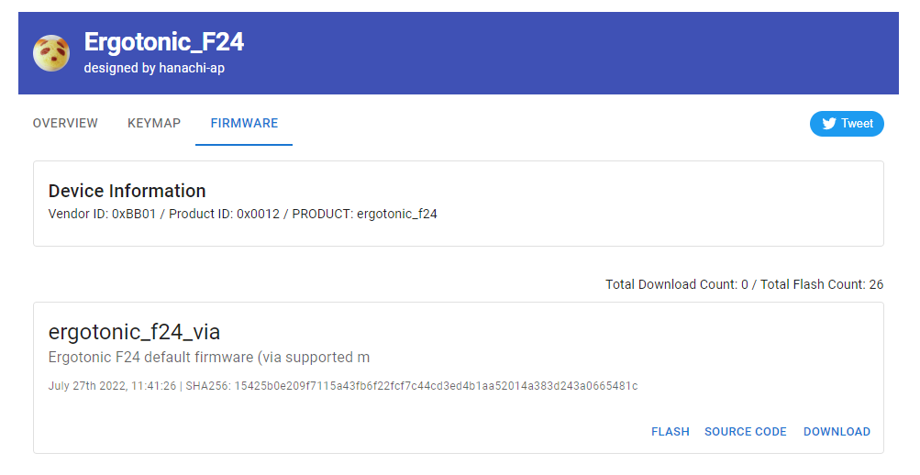
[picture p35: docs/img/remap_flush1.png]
   

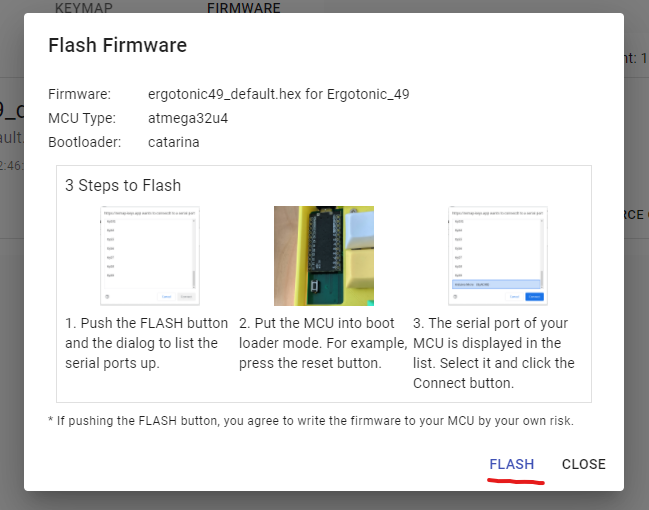
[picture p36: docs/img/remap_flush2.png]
   

- シリアルポート選択のポップアップ画面が出たら、キーボードのリセットボタンを
  押します。

- シリアルポートの一覧に ’Arduino Micro (COMxx)' とう行が追加されるので
  それを選択して ’接続’ をクリックします。
   
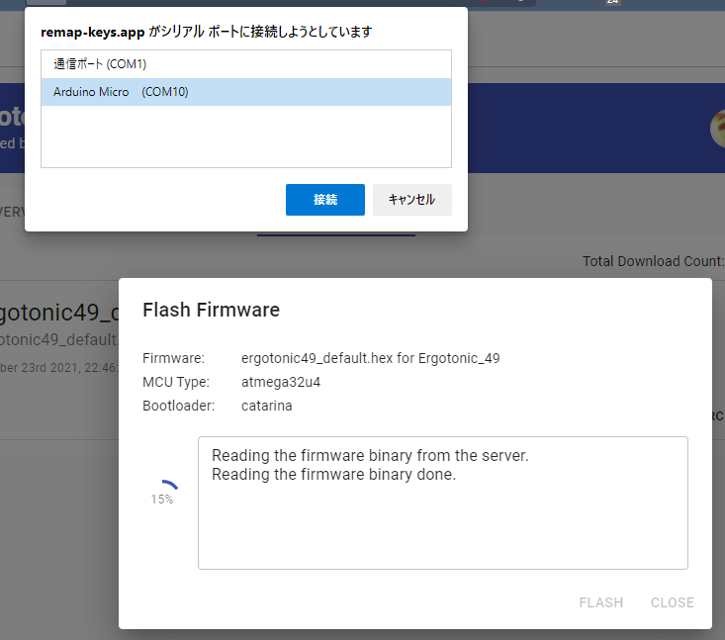
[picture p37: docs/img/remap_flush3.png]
   

- Firmware書き込みが正常に完了することを確認します。

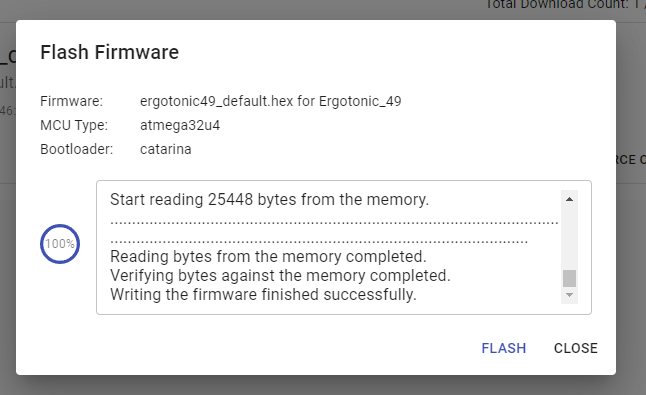
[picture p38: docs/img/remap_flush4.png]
   

TIPS:

- REMAPの画面や操作方法は日々更新されるため、実際の操作はREMAPに記載の
内容をよく確認の上で行うようにしてください。

- QMK Toolboxを利用する場合はファームウェアは下記から取得してください。
   [ergotonic_f24_default.hex](../firmware/binary/hanachi_ap_ergotonic_f24_default.hex) してください。

## 左右をケーブルで結んで確認

- パソコンとProMicroのケーブルを取り外します。
- TRRSケーブルで左右のPCBを接続します。
- 左側のPCBにUSBケーブルを接続します

NOTE:
 通常の利用時も、USBケーブルは左側に接続します。

## キーが反応することを確認する

全体を組み立てる前にはんだ付けに問題がないかをこの時点で確認します。

Chromeブラウザで[REMAPサイト](https://remap-keys.app/configure)を開きます。

- Ergotonic_F24 という名称で認識され、キーマップ定義画面が開きます。
- 画面右側の  '...' メニューから "Test Matrix mode"に移ります。
- PCBにはんだ付けしたソケットにピンセットの先を差し込んでキーが押された状態を再現します。
- 画面上でキーが押された状態になったことを確認します

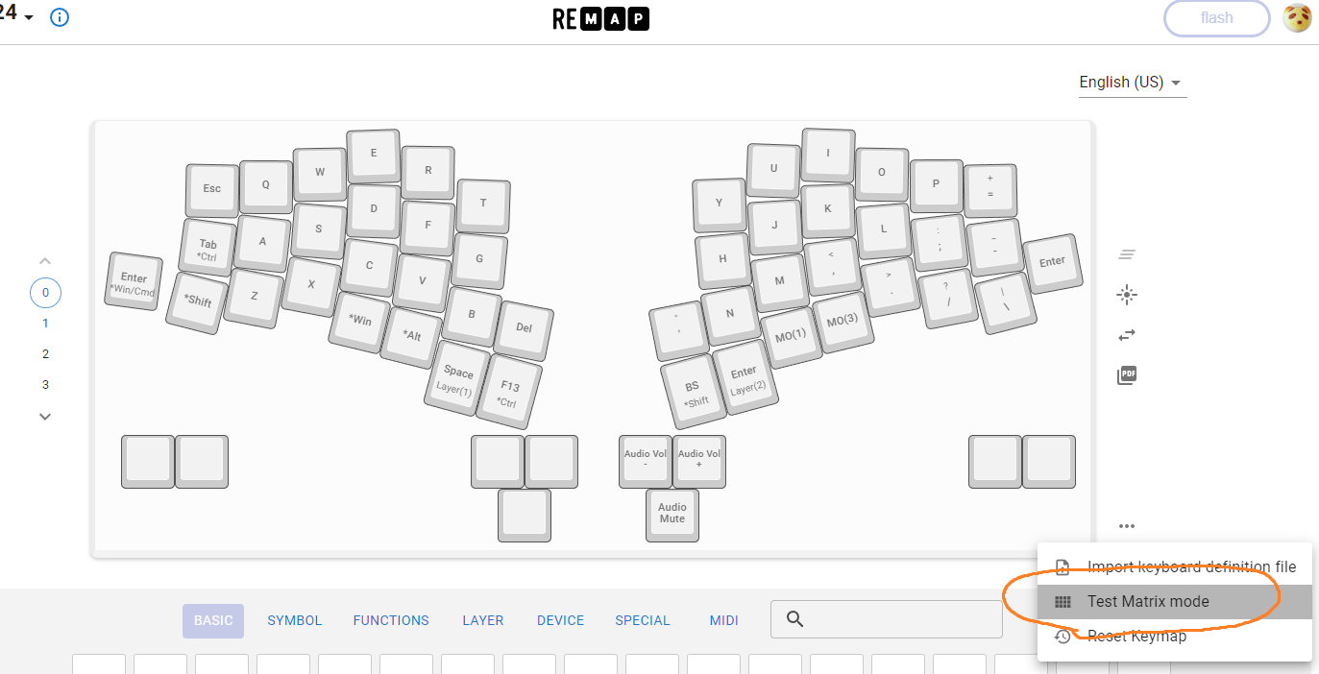
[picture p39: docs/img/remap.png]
  

トラブルシュート:
  - [キーが反応しない](07_troubleshoot.md)

----
 [>>Next: 組み立て](05_assembly.md)

[Index](index.md)

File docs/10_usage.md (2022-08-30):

# Ergotonic F24の使い方

## 1．左右のキーボードをケーブルで接続します
- TRRSケーブル もしくは 専用のコネクタ付きケーブルを使用します
- これらのケーブルはホットプラグには対応していません。
  必ず USBケーブルが抜かれている状態で、抜き挿しするようにしてください
- USBケーブルがつながった状態で抜き差しした場合、マイコンが動作異常したり最悪は故障したりする場合もありますので注意してください。
  
##  2． 左手側とPCとをUSBケーブルで接続します
- USBケーブルは、左手側のProMicroに差し込むようにしてください。
- 右手側に刺した場合にはキーの定義が左右で反転します。
- もし右手側にUSBケーブルを刺したい事情がある場合は、ファームウェアのプログラム修正で対応できます。

## 3．キーマップをカスタマイズします
Remapに登録しているDefault Firmwareは非常にシンプルなキー定義しかされていない状況ですので、本格的に使うためにはキーマップを好みに合わせて定義してください。

初めから全てのキーマップをカスタマイズする手間を省くために、ReMAPでキーマップ共有されている ”default_keymap” をロードしてから、
それをベースにカスタマイズを始めることをオススメします。

- キーボードとPCをつないだ状態でChromeブラウザで[https://remap-keys.app/](https://remap-keys.app/)にアクセスして下さい。

- Ergotonic_F24のカスタマイズ画面まで遷移したら、画面右側にある ”Save/Restore a keymap"のボタンをクリックし default_keymapを読み込んでみてください。

- ”default_keymap"では0から3までの4つのレイヤーに各機能が定義されています。 

  - レイヤー0  : 基本のアルファベット
  - レイヤー1 : 数字、記号
  - レイヤー2  : カーソル移動、ファンクションキー
  - レイヤー3  : LED操作などキーボードシステム設定

自分が使いやすいと思うように自由にカスタマイズすることは自作キーボードの楽しみの一つなので、標準キーマップにとらわれず色々と試してみるのが良いと思います。

もし便利な使い方があればぜひ他のユーザさんと共有してください。

## 可動ギミックのコツ
- 可動ギミックは日常から常に変形させて愛でるようなものではなく、利用者の好みのポジションを見つけたらそこでネジを固定して運用するようなことを想定しています。
  
- 可動ギミックは、プレートの面摩擦をネジのトルクで調整する方式です。
  - 元々はこのような変形に適した素材や構造ではないので頻繁に変形するような場合はどうしても無理がかかります。
  - プレート面に擦過傷がついたり、塗装が削れたりする場合があります。
- 緩めたネジは外れて失くしやすいので注意してください。
 
## QMK Firmwareを編集してコンパイルするには

Ergotonic F24は[QMK Firmware](https://docs.qmk.fm/)というオープンソースとして開発されているファームウェアを利用しいています。

QMKにはとても沢山の機能が用意されていて、より自由な設定を行うことができます。
しかしそのためにはプログラミング言語(C言語)やPC上での黒い画面(コンソール)でコマンドを使ったコンパイル操作を行う必要があります。

Ergotonic F24のファームウェアは [ここ](https://github.com/hanachi-ap/ergotonic_f24)から参照できます。
もしこれを見て行けそうだ! と感じたらぜひQMK Firmwareのカスタマイズに挑戦してみて下さい。

(公開しているDefault Firmware はQMK Firmware 0.15.6でコンパイルしていますが、
最新のQMKバージョンではエラーが出るかもしれません。)

----
 [Index](index.md)

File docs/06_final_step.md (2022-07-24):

[<<Prev: 組み立て](05_assembly.md)  

# 6. 最後のステップ

## キースイッチを取り付ける

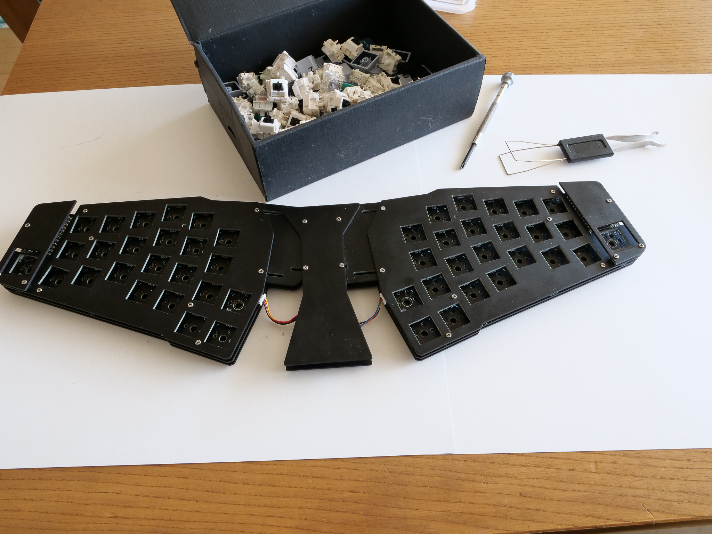
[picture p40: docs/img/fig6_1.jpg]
あともう一息
  

キースイッチをトッププレート側から取り付けます。

NOTE:

  - キースイッチを取り付ける際にはまっすぐ上から慎重に差し込むようにします。
  - スイッチのピンは曲がりやすいので注意してください。 ピンが曲がったまま無理矢理取り付けるとそのキーは反応しなくなります。
  - ピンが曲がってしまった場合でも、一度引き抜いてラジオペンチの先端で慎重に伸ばせばリカバリ可能です。

## キーキャップを取り付ける

お好きなキーキャップ取り付けます。

## 最終動作確認

最後の確認を行って完成です。
- すべてのキーが反応すること
- すべてのLEDが点灯すること

うまく行かないことがある場合は → [トラブルシュート](07_troubleshoot.md)

## 問題がなければこれで作業は完了です!

素敵な写真を撮ってSNSで自慢しましょう。

----
 [>>Next: トラブルシュート](07_troubleshoot.md)

[Index](index.md)

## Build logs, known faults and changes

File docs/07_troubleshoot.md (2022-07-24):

[<<Prev: 最後のステップ](06_final_step.md)  

# 7. トラブルシュート

## LED関連トラブル
### LEDが点灯しない

  - 全てのLEDは番号順に数珠つなぎになっていています。
    - 途中で不良のLEDがあるとそれ以降のLEDがすべて点灯しなくなる特徴があります。
    - 点灯しないLEDだけでなくその一つ前のLEDもよく調べて下さい。
  - LEDの取り付け方向が正しいか
     - LEDは極性があり、取り付ける向きが決まっています。
     - LEDの切り欠きのある足と、PCBのシルクの方向が合っているか
     - オモテウラが間違っていないか
     - 取り付け方向に間違いがあるとLEDが光らないだけでなく、キーボードとしての全機能が動かなくなる場合もあるので注意
  - LEDのハンダ付けに問題はないか
    - はんだ付けに不良があると、全く点灯しない、発色が変わらない、激しく明滅するなどの現象が起こります。
    - はんだ付け忘れはないか
    - LEDの足が浮いている部分はないか
    - 芋はんだ、はんだ量不足、ブリッジなどはんだ不良はないか

## キーが反応しない

### 特定のキーが反応しない
 
大抵の場合は下記の原因が考えられるので落ち着いて調べます

- キースイッチのピン(足)が折れ曲がっていないか
- ダイオードの向きが逆でないか
- ダイオードのはんだ付け不良はないか
- キーソケットのはんだ付け不良はないか
- そもそも、そのキーにキーコードが割り当てられていない(レイヤー切り替え等)

### どのキーも反応しない

ProMicro周辺を重点に調べます

- PCとキーボードが正しくUSBで接続されているか。
  通電するとProMicroに実装されたLEDが点灯します。
- ProMicroに正しくファームウェアが書き込まれているか
- ProMicroとコンスルーのはんだ付けに不良はないか
- ProMicroのピンヘッダが曲がっていないか

### ProMicroのLEDが点灯しない

純正品、コピー品により仕様は異なりますが、多くの場合は正常に動作している場合はProMicroの
LEDが緑色に点灯します。

- USBケーブルはデータ通信用のものを使用しているか
- ProMicroのはんだがショートしていないか
- RGB LEDの向きが正しいか(間違っている場合、回路がショートしてProMicroが動作しない場合もあります)

----
 [>>Next: 参考情報](08_reference.md)

[Index](index.md)

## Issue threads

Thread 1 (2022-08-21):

dead links in build guide

teppeis, 2022-08-21:
いくつかリンク切れを見つけたので報告します。

[遊舎工房(ロータリーエンコーダ(ノブ付き)](https://shop.yushakobo.jp/collections/keyboard-parts/products/pec12r-4222f-s0024)
https://github.com/hanachi-ap/ergotonic_f24/blob/006d9dbf5f218238c52e51f8aaa2f3123f591980/docs/01_preparation.md

ゆかりキーボードファクトリ https://eucalyn.shop/
https://github.com/hanachi-ap/ergotonic_f24/blob/006d9dbf5f218238c52e51f8aaa2f3123f591980/docs/08_reference.md

チートシート [keymap_cheatsheet_ergotonic_49.pdf](img/keymap_cheatsheet_ergotonic_49.pdf)
https://github.com/hanachi-ap/ergotonic_f24/blob/006d9dbf5f218238c52e51f8aaa2f3123f591980/docs/09_customize.md

hanachi-ap, 2022-08-22:
@teppeis  指摘ありがとうございます。各リンク修正しました (チートシートは記事から削除)

Closed 2022-08-22.

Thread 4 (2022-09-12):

スイッチが、行 または 列単位で反応しない場合がある

hanachi-ap, 2022-09-12:
バージョン: v1r3
基板: PCB 右 もしくは 左
問題: ダイオード、ソケット、ProMicro等一通り実装が終わった後にキー反応を確認すると、列 または 行の単位で反応しない場合が 稀にある

これまで ユーザから2例報告されているが、反応しなくなるキーの位置は確定していない。

hanachi-ap, 2022-09-12:
下記の状況の切り分け結果から、問題は ProMicroのコンスルーと、PCB側のスルーホールとの接触不良によるものと判断。

- ProMicroのPinとPCBで本来つながっているパッド部分をテスタで測定すると問題の箇所だけ導通しない
- コンスルーの足を少し曲げると導通する
- スルーホールの穴部分を軽く削ったりすると導通するう

hanachi-ap, 2022-09-12:
おそらく今回PCBの製造の段階での不良が混入している可能性が高い。

問題のあるスルーホールを目視やマイクロスコープで観察しても、特に外見的な異常を見つけることができず、ユーザへの出荷前に完全に不良を排除することは困難。

同様の問題に遭遇した際に、ProMicroのピンを少し曲げ気味にする、PCBの穴を少しホジホジするといった対応をトラブルシュートに記載する。

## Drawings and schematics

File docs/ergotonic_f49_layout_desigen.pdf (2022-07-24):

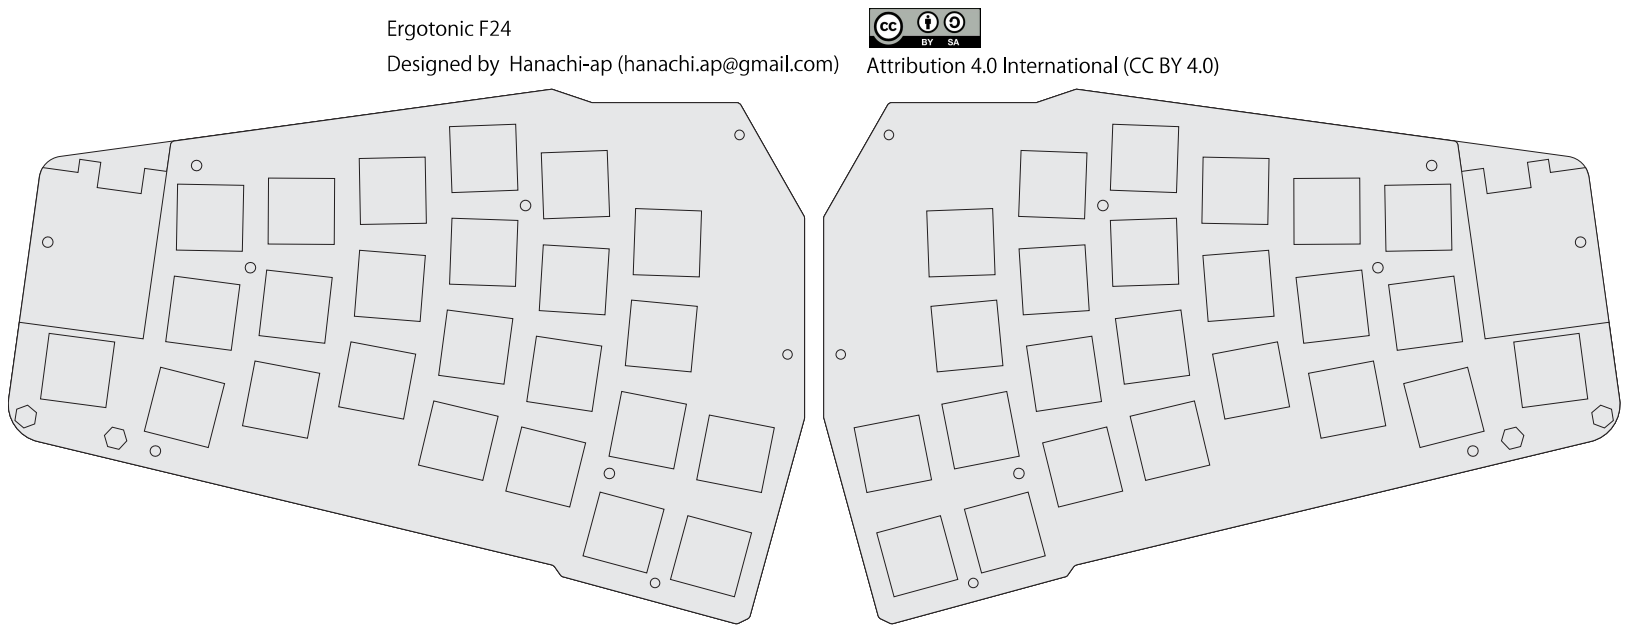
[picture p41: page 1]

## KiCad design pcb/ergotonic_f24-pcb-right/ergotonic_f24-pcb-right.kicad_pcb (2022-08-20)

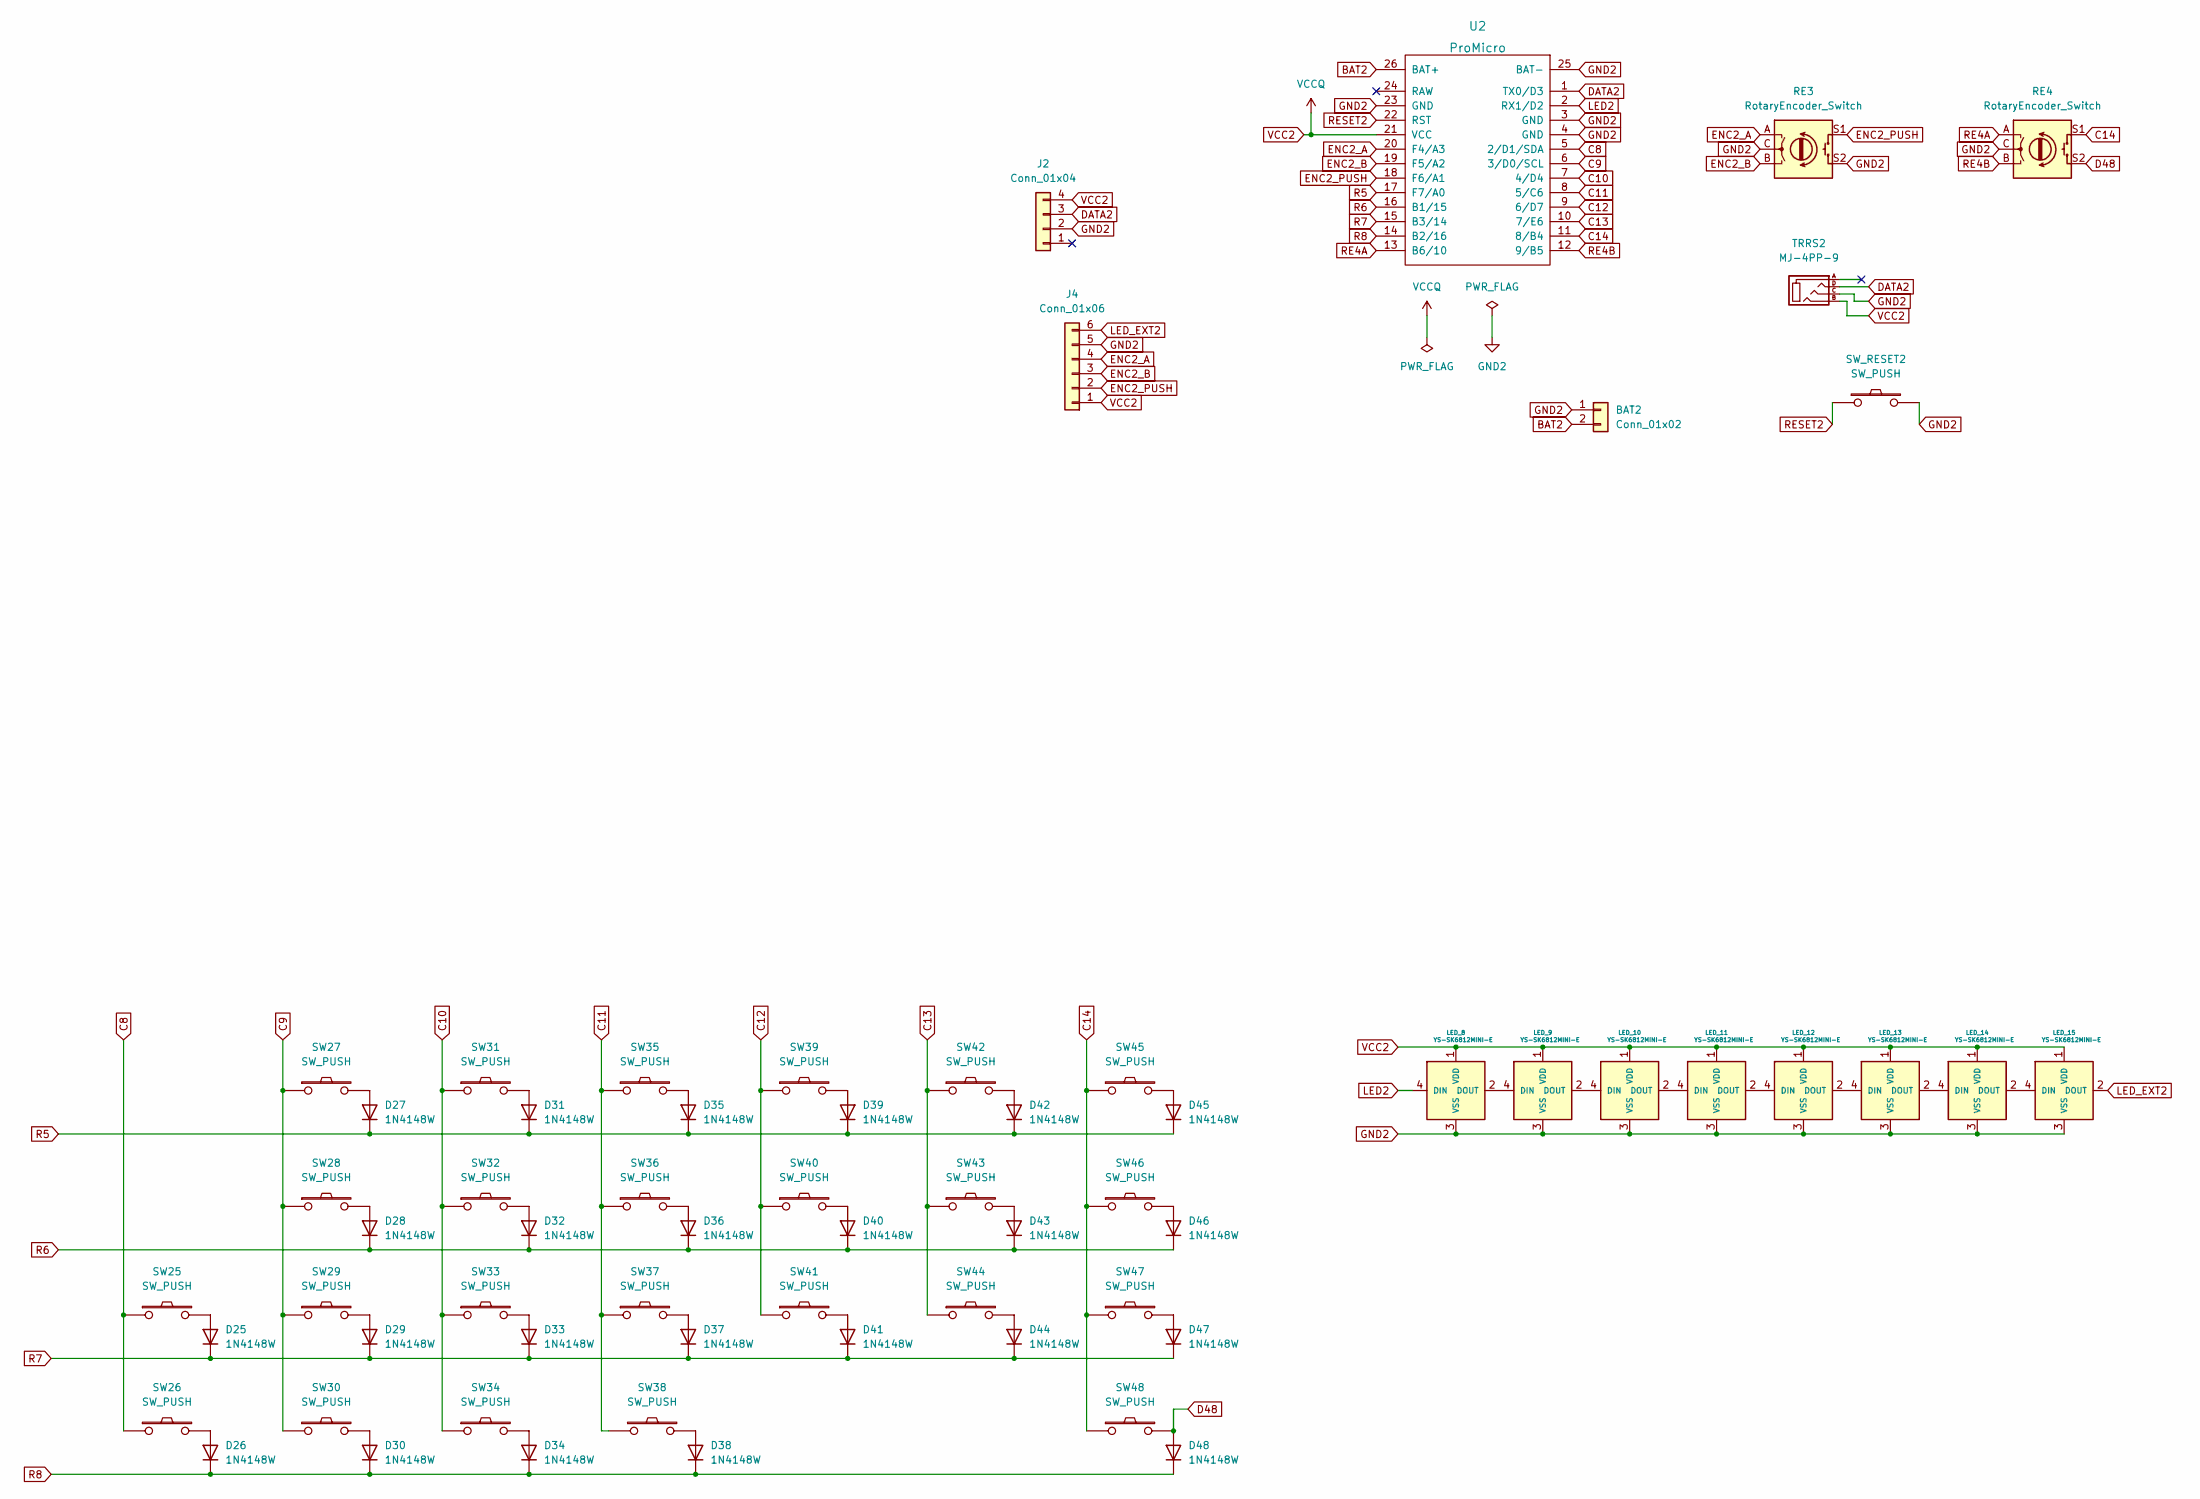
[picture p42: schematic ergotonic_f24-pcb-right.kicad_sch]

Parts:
BAT2: Conn_01x02; PinHeader_1x02_P2.54mm_Vertical
D25, D26, D27, D28, D29, D30, D31, D32, D33, D34, D35, D36, D37, D38, D39, D40, D41, D42, D43, D44, D45, D46, D47, D48: 1N4148W; D3_SMD_v2
J2: Conn_01x04; JST_SH_BM03B-SRSS-TB_1x04-1MP_P1.00mm_Vertical
J4: Conn_01x06; JST_SH_BM03B-SRSS-TB_1x06-1MP_P1.00mm_Vertical
LED_8, LED_9, LED_10, LED_11, LED_12, LED_13, LED_14, LED_15: YS-SK6812MINI-E
RE3, RE4: RotaryEncoder_Switch; RotaryEncoder_Alps_EC11E-Switch_Vertical_H20mm_rev2
SW25, SW26, SW27, SW28, SW29, SW30, SW31, SW32, SW33, SW34, SW35, SW36, SW37, SW38, SW39, SW40, SW41, SW42, SW43, SW44, SW45, SW46, SW47, SW48: SW_PUSH; CherryMX_Hotswap
SW_RESET2: SW_PUSH; ResetSW_1side
TRRS2: MJ-4PP-9; MJ-4PP-9_1side
U2: ProMicro

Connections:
BAT2: BAT2.2, U2.26 (BAT+)
C8: SW25.1, SW26.1, U2.5 (2/D1/SDA)
C9: SW27.1, SW28.1, SW29.1, SW30.1, U2.6 (3/D0/SCL)
C10: SW31.1, SW32.1, SW33.1, SW34.1, U2.7 (4/D4)
C11: SW35.1, SW36.1, SW37.1, SW38.1, U2.8 (5/C6)
C12: SW39.1, SW40.1, SW41.1, U2.9 (6/D7)
C13: SW42.1, SW43.1, SW44.1, U2.10 (7/E6)
C14: RE4.S1, SW45.1, SW46.1, SW47.1, SW48.1, U2.11 (8/B4)
D48: D48.2 (A), RE4.S2, SW48.2
DATA2: J2.3, TRRS2.D, U2.1 (TX0/D3)
ENC2_A: J4.4, RE3.A, U2.20 (F4/A3)
ENC2_B: J4.3, RE3.B, U2.19 (F5/A2)
ENC2_PUSH: J4.2, RE3.S1, U2.18 (F6/A1)
GND2: BAT2.1, J2.2, J4.5, LED_8.3 (VSS), LED_9.3 (VSS), LED_10.3 (VSS), LED_11.3 (VSS), LED_12.3 (VSS), LED_13.3 (VSS), LED_14.3 (VSS), LED_15.3 (VSS), RE3.C, RE3.S2, RE4.C, SW_RESET2.2, TRRS2.C, U2.3 (GND), U2.4 (GND), U2.23 (GND), U2.25 (BAT-)
LED2: LED_8.4 (DIN), U2.2 (RX1/D2)
LED_EXT2: J4.6, LED_15.2 (DOUT)
unnamed: D25.2 (A), SW25.2
unnamed: D26.2 (A), SW26.2
unnamed: D27.2 (A), SW27.2
unnamed: D28.2 (A), SW28.2
unnamed: D29.2 (A), SW29.2
unnamed: D30.2 (A), SW30.2
unnamed: D31.2 (A), SW31.2
unnamed: D32.2 (A), SW32.2
unnamed: D33.2 (A), SW33.2
unnamed: D34.2 (A), SW34.2
unnamed: D35.2 (A), SW35.2
unnamed: D36.2 (A), SW36.2
unnamed: D37.2 (A), SW37.2
unnamed: D38.2 (A), SW38.2
unnamed: D39.2 (A), SW39.2
unnamed: D40.2 (A), SW40.2
unnamed: D41.2 (A), SW41.2
unnamed: D42.2 (A), SW42.2
unnamed: D43.2 (A), SW43.2
unnamed: D44.2 (A), SW44.2
unnamed: D45.2 (A), SW45.2
unnamed: D46.2 (A), SW46.2
unnamed: D47.2 (A), SW47.2
unnamed: LED_8.2 (DOUT), LED_9.4 (DIN)
unnamed: LED_10.2 (DOUT), LED_11.4 (DIN)
unnamed: LED_9.2 (DOUT), LED_10.4 (DIN)
unnamed: LED_11.2 (DOUT), LED_12.4 (DIN)
unnamed: LED_12.2 (DOUT), LED_13.4 (DIN)
unnamed: LED_13.2 (DOUT), LED_14.4 (DIN)
unnamed: LED_14.2 (DOUT), LED_15.4 (DIN)
R5: D27.1 (K), D31.1 (K), D35.1 (K), D39.1 (K), D42.1 (K), D45.1 (K), U2.17 (F7/A0)
R6: D28.1 (K), D32.1 (K), D36.1 (K), D40.1 (K), D43.1 (K), D46.1 (K), U2.16 (B1/15)
R7: D25.1 (K), D29.1 (K), D33.1 (K), D37.1 (K), D41.1 (K), D44.1 (K), D47.1 (K), U2.15 (B3/14)
R8: D26.1 (K), D30.1 (K), D34.1 (K), D38.1 (K), D48.1 (K), U2.14 (B2/16)
RE4A: RE4.A, U2.13 (B6/10)
RE4B: RE4.B, U2.12 (9/B5)
RESET2: SW_RESET2.1, U2.22 (RST)
VCC2: J2.4, J4.1, LED_8.1 (VDD), LED_9.1 (VDD), LED_10.1 (VDD), LED_11.1 (VDD), LED_12.1 (VDD), LED_13.1 (VDD), LED_14.1 (VDD), LED_15.1 (VDD), TRRS2.B, U2.21 (VCC)

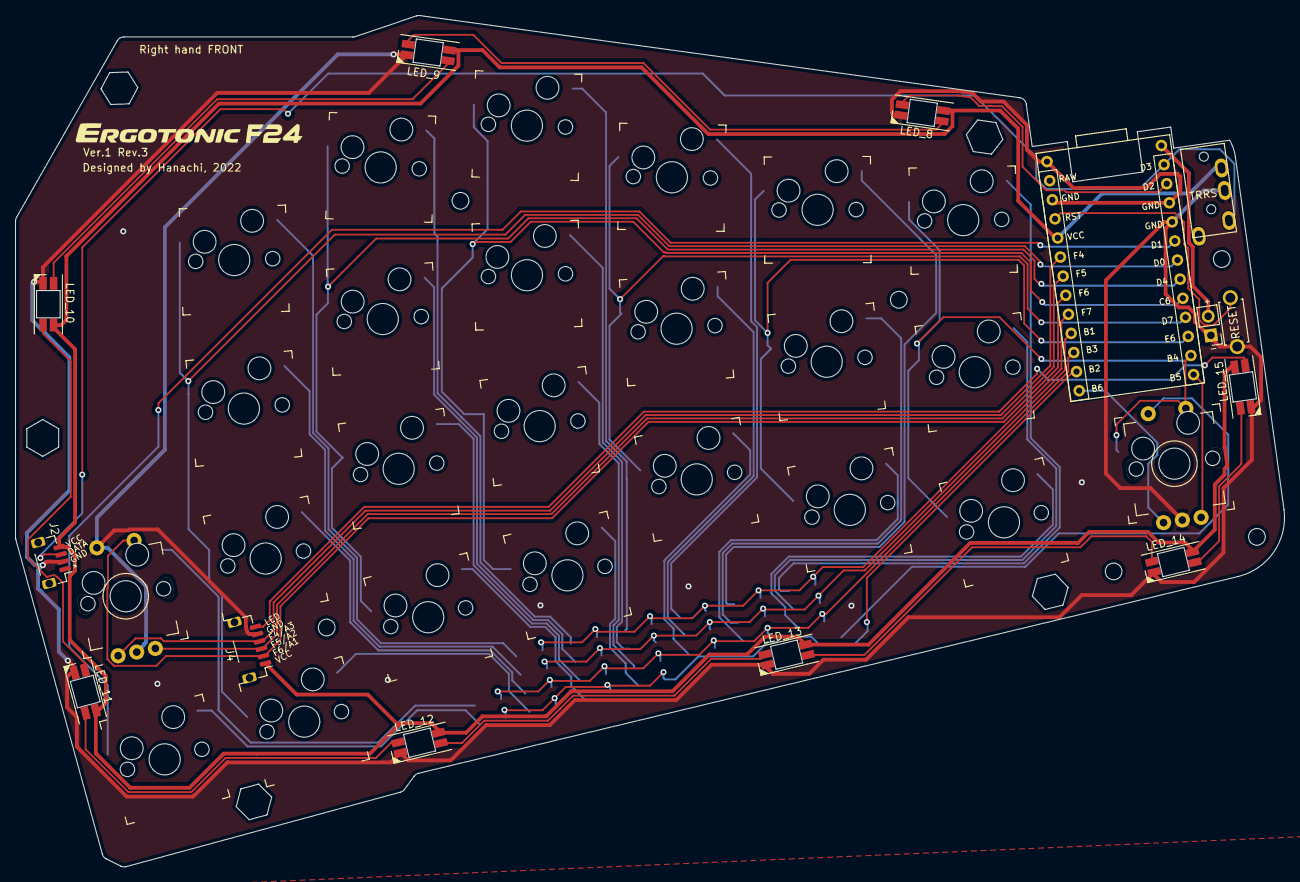
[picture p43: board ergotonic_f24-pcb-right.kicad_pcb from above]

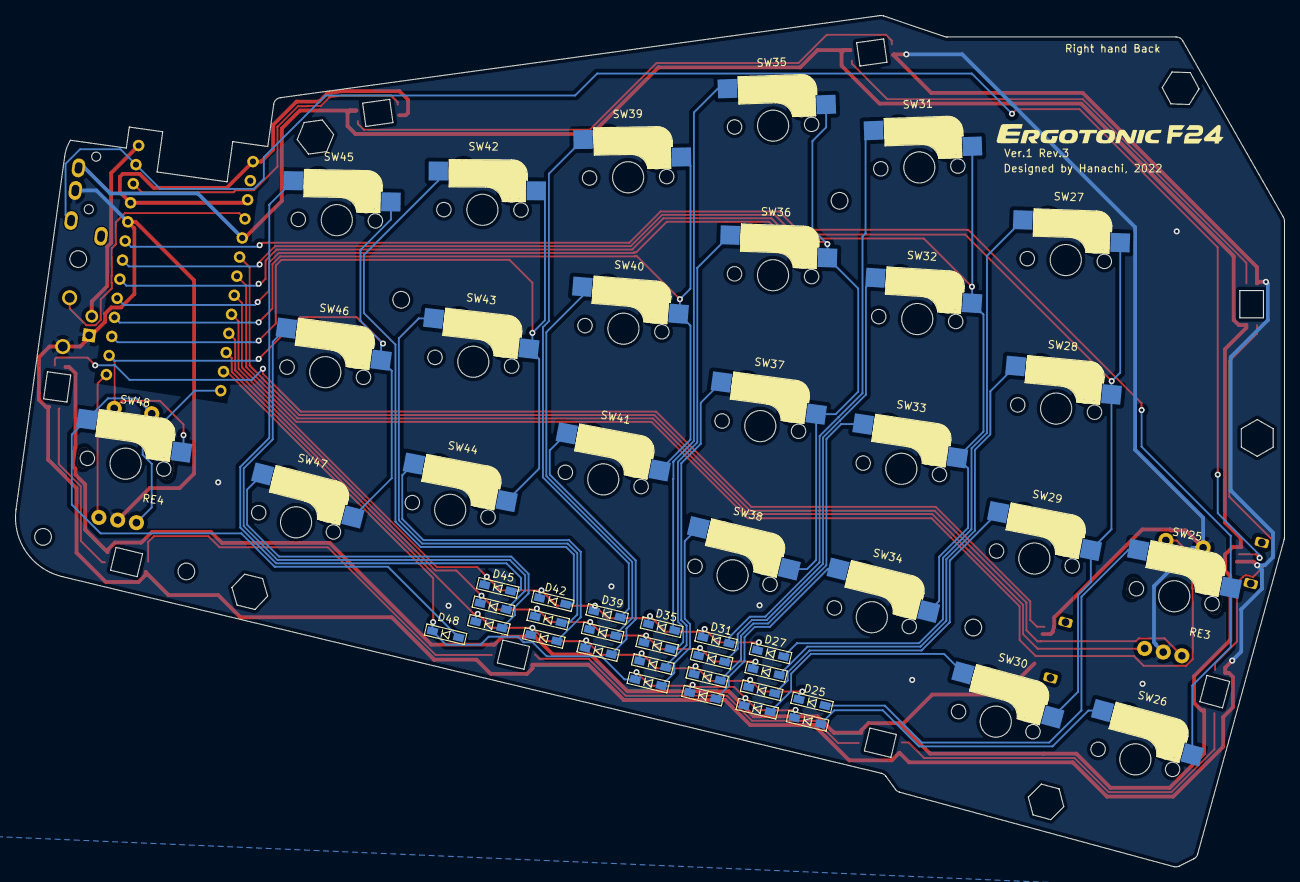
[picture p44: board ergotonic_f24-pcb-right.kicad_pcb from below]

Board: 2 copper layers, 167.2 x 112.2 mm, 64 parts (24 on the bottom side), 54 nets.

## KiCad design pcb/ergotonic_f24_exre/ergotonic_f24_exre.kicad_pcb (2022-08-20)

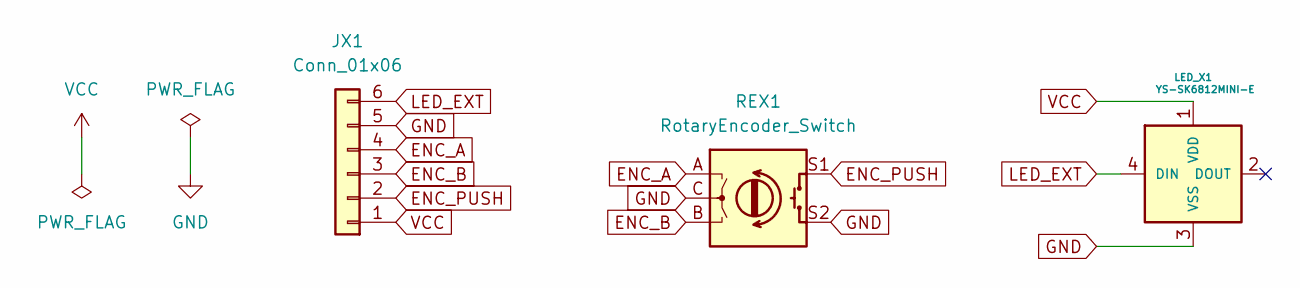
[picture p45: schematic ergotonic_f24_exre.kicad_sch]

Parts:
JX1: Conn_01x06; JST_SH_BM03B-SRSS-TB_1x06-1MP_P1.00mm_Vertical
LED_X1: YS-SK6812MINI-E
REX1: RotaryEncoder_Switch; RotaryEncoder_Alps_EC11E-Switch_Vertical_H20mm_rev2

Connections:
ENC_A: JX1.4, REX1.A
ENC_B: JX1.3, REX1.B
ENC_PUSH: JX1.2, REX1.S1
GND: JX1.5, LED_X1.3 (VSS), REX1.C, REX1.S2
LED_EXT: JX1.6, LED_X1.4 (DIN)
VCC: JX1.1, LED_X1.1 (VDD)

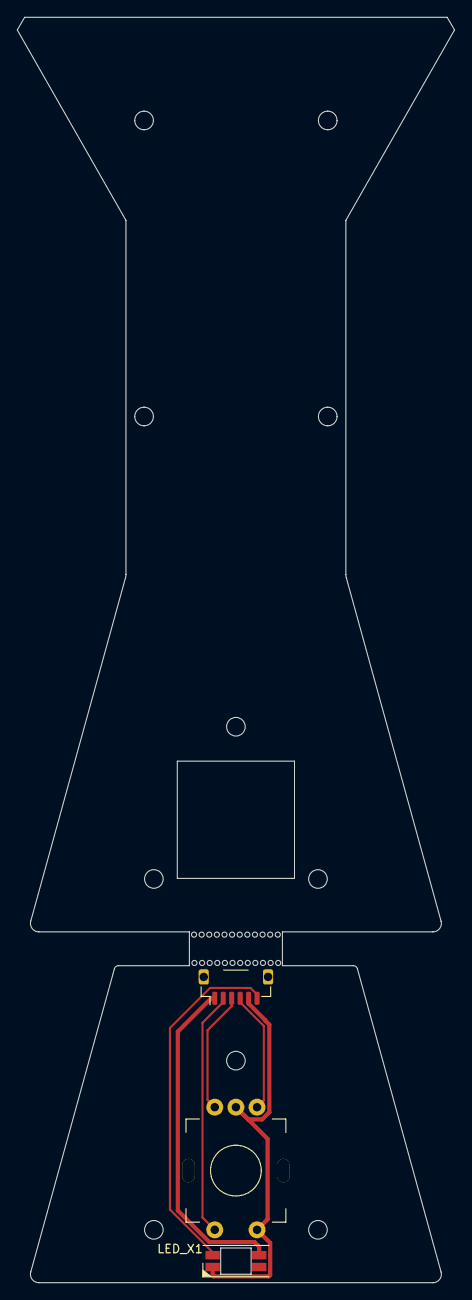
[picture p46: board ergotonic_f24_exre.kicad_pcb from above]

Board: 2 copper layers, 51.7 x 149.6 mm, 3 parts (0 on the bottom side), 6 nets.

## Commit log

2022-03-21 modified firmware (added encoder feature)
2022-03-21 fix: encoder control
2022-04-01 fix; encoder support in VIA
2022-04-01 update: firmware binary (support encoder in VIA)
2022-07-23 ver1 rev2 base
    [ergotonic_f24-pcb-left-BOM.xlsx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]
2022-07-24 v1r2: Preparing for publication
    [ergotonic_f24-B_Cu.gbr, ergotonic_f24-B_Mask.gbr, ergotonic_f24-B_Paste.gbr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]
2022-08-20 Version 1 Revision 3
    [ergotonic_f24-pcb-left-B_Cu.gbr, ergotonic_f24-pcb-left-B_Mask.gbr, ergotonic_f24-pcb-left-B_Paste.gbr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]
2022-09-03 gerber data is no longer publicly available
    [ergotonic_f24-pcb-left-B_Cu.gbr, ergotonic_f24-pcb-left-B_Mask.gbr, ergotonic_f24-pcb-left-B_Paste.gbr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]
2022-09-18 update: acrylic cut data
2022-09-18 update aclylic cut data
2022-09-22 fix aclylic cut data
    [ergotonic_f24_v1r3_2_acrylic_cut.dxf]
2022-09-22 fix aclylic cut data (add zip file)
2024-07-30 Added STL files for variable wing mechanism
    [f24 - knob.stl, f24 - base.stl, f24 - top.stl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]
2024-08-16 add stl files
    [f24 - knob.stl, f24 - base.stl, f24 - drumette-l.stl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]
